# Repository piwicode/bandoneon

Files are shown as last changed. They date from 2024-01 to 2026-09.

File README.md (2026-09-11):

Bandolibre keyboard

🇬🇧 **English** | 🇫🇷 [Français](README.fr.md) | 🇪🇸 [Español](README.es.md)

# Bandolibre

An open-source MIDI controller that brings the Argentine bandoneon into the digital age.

**Bandolibre focuses on one goal:** turning key presses and bellows movement into MIDI — faithfully, instantly, and without the cost or noise of an acoustic instrument. Plug it into any computer, tablet, or phone over USB and you're ready to play, compose, or practice.

An open initiative by [L'Atelier du bandonéon libre](https://github.com/bandolibre)

---

## See it play

Bandolibre demo with a clarinet virtual instrument (https://youtu.be/6s1wlRKlAk4)

Watch the demos: [with a clarinet virtual instrument](https://youtu.be/6s1wlRKlAk4) · [with strings virtual instruments](https://youtu.be/nJ0j7DtbYDk).

---

## Who is it for?

- **Students** who don't own an instrument yet and want to start learning
- **Players** who want to practice silently — at home, on the road, at any hour
- **Composers** entering scores into notation software one note at a time
- **Musicians** triggering synths and samplers on stage or in the studio

---

## How it works

- **142-key Rheinische Lage layout** — both hands, exact fingering of the Argentine bandoneon
- **Hall-effect sensors** on every key — no mechanical contact, no wear, scanned 2400 times per second
- **Blade spring + sensor pair** for the bellows — measures push/pull effort and emits MIDI CC#11 (Expression), just like the real thing
- **Two 6.35 mm expression pedal inputs** — compatible with M-Audio EX-P pedals; pedal 1 sends CC#1 (Modulation), pedal 2 sends CC#4 (Foot Controller)
- **USB-MIDI** out of the box — plug into any DAW, notation app, or synth; no drivers needed

---

## Features

**Keyboard tuning** — a button cycle through the three keyboard layouts: Rheinische Tonlage (bisonoric, 142 tones), Peguri, or Manoury.

**Table mode** — a button toggles table mode: keys fire immediately at fixed velocity, no bellows movement required. Handy for entering a score note by note without working the bellows.

**Play anywhere** — Bandolibre is bus-powered over USB; any phone, tablet, or laptop with a soft synth becomes the sound engine. A small USB hub with a headphone jack and a power pass-through gives you audio, charging, and MIDI from a single cable — tested and pocket-sized.

**Adaptable** — standard USB-MIDI is compatible with the whole adapter ecosystem: plug in a USB Bluetooth MIDI adapter to play wirelessly, or a USB-to-DIN-5 adapter to drive vintage hardware synths.

---

## Anyone can build it

This is a fully open DIY project. PCBs are designed for economic JLCPCB two-layer fabrication — affordable and easy to order. The mechanical parts are 3D-printable (a FabLab near you works great). Firmware is open-source and flashable with a standard [ST-LINK probe](https://www.st.com/en/development-tools/stlink-v3minie.html) and a [TC-2070-IDC-050](https://www.tag-connect.com/product/tc2070-idc-050) cable.

Building one costs about as much as a decent MIDI keyboard or a good pair of studio headphones like the DT-770 Pro.

---

## Bill of Materials

| Part | Qty | Notes |
|---|-----|---|
| 3D-printed body parts + 71 keys | — | ~880 g filament, ~24 h print time, [STEP files](https://github.com/bandolibre/bandolibre.github.io/releases)|
| Electronics board: Main, left and right PCBs  | 1 | [EasyEDA design](boards), [Gerber files](https://github.com/bandolibre/bandolibre.github.io/releases) |
| Hall-effect switches | 71 | [GATERON Low Profile Magnetic Jade HE](https://www.gateron.com/products/gateron-low-profile-magnetic-jade-switch?VariantsId=10872) |
| Bellows spring strip | 1 | [65Mn spring steel, 1.2 × 40 × 300 mm](https://fr.aliexpress.com/item/1005006952720032.html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) |
| Permanent magnets 14.5 × 6 × 2 mm | 2 |  |
| M4 × 30 socket head cap, stainless A2 | 4 | [supplier](https://www.vis-express.fr/vis-metaux-inox-a2-chc-btr-cle-de-8-hc8-filetage-total-din-912-din-912-iso-4762/36756-927484-vis-metaux-inox-a2-chc-btr-cle-de-3-hc3-m4x40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)|
| M4 × 10 × 0.8 flat washer, stainless A2 | 4 | [supplier](https://www.vis-express.fr/rondelle-plate-m-inox-a2-nfe-25513vs-nfe25513-grade-c/36925-940576-rondelle-plate-m4x10x08-m-inox-a2.html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)|
| M3 × 6 socket head cap, stainless A2 | 19 | [supplier](https://www.vis-express.fr/vis-metaux-inox-a2-chc-btr-cle-de-8-hc8-filetage-total-din-912-din-912-iso-4762/36726-2595617-vis-metaux-inox-a2-chc-btr-cle-de-25-hc25-m3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)|
| M3 × 8 socket head cap, stainless A2 | 11 | [supplier](https://www.vis-express.fr/vis-metaux-inox-a2-chc-btr-cle-de-8-hc8-filetage-total-din-912-din-912-iso-4762/36728-2610009-vis-metaux-inox-a2-chc-btr-cle-de-25-hc25-m3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) |
| M3 × 12 socket head cap, stainless A2 | 4 | [supplier](https://www.vis-express.fr/vis-metaux-inox-a2-chc-btr-cle-de-8-hc8-filetage-total-din-912-din-912-iso-4762/36731-2616466-vis-metaux-inox-a2-chc-btr-cle-de-25-hc25-m3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) |
| M3 × 18 socket head cap, stainless A2 | 4 | [supplier](https://www.vis-express.fr/vis-metaux-inox-a2-chc-btr-cle-de-8-hc8-filetage-total-din-912-din-912-iso-4762/36734-2596394-vis-metaux-inox-a2-chc-btr-cle-de-25-hc25-m3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) |
| Adhesives | 2 drops | Loctite 480 |
| USB Type-B cable | 1 | |
| Ribbon cable, FC 1.27 mm, 12P (2×6), 10 cm | 2 | [supplier](https://fr.aliexpress.com/item/1005005058041580.html) |

The full list, including tools and consumables, is in [`documentation/assembly_instructions.md`](documentation/assembly_instructions.md).

They are best built in batches of five — JLCPCB minimum orders make that the natural unit. Team up with friends or reach out to [L'Atelier du bandonéon libre](https://github.com/bandolibre) to express interest in a community build.

At fifty units, PCB fabrication and Gateron switches — the two biggest line items — drop by half again.

---

## Design

overview

The mechanical parts are modeled in Onshape — [the full 3D model](https://cad.onshape.com/documents/313e70e978bf056a8dd7d76c/v/5c5fbc4088ac379c1bd1b53a/e/c6a89cb028bdc195ff70596f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) is public and interactive. Reference [photography](keyboard_picture/) of real instruments was used to accurately reproduce the shape, key placement, and keyboard tilt of both hands.
handle_layout
keyboard_layout

The PCBs are designed with EasyEDA.
3d_pcb

The bellows is replaced by a **blade spring instrumented with two Hall-effect sensors** that read its flexion. Load cell solutions were ruled out early — they are too rigid and remove the tactile feedback players rely on to feel and modulate their effort — it plays like pressing on a wall. The blade spring preserves that proprioceptive feedback while being simple and durable. Blade thickness can be chosen to tune the instrument's stiffness, from light to firm.

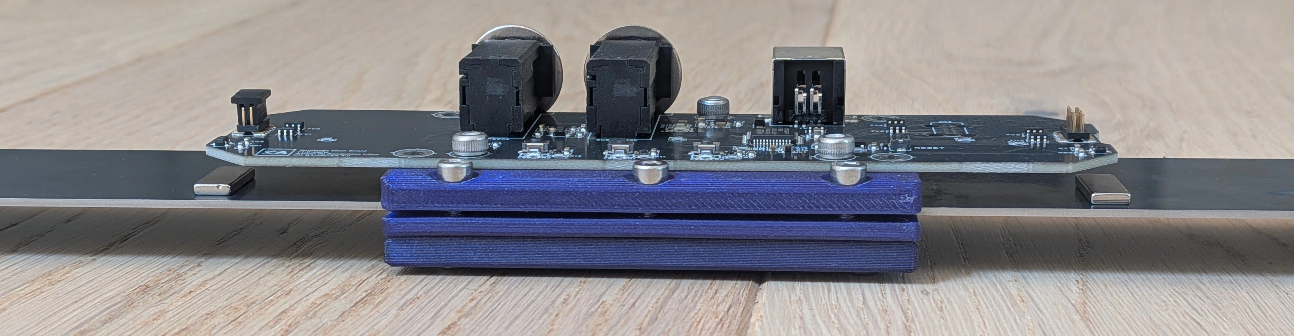
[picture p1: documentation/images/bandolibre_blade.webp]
blade spring


A sensitivity selector button cycles through three amplification levels so the player can adjust how much bellows travel is needed to reach full expression — useful for quiet practice or a stiffer spring.

For a detailed breakdown of the firmware behavior and controls, see [`documentation/features.md`](documentation/features.md).

---

## Build it

- **Hardware & assembly:** see [`documentation/assembly_instructions.md`](documentation/assembly_instructions.md)
- **Firmware:** see [`code/`](code/) — build with `just build` and `just flash`, flash via ST-LINK

---

## Sound

The best match so far is the **SWAM** family of simulation instruments from [Audio Modeling](https://audiomodeling.com/): they are physically modelled rather than sampled, so CC#11 continuously drives the model itself. Bellows intensity comes out as real dynamics — timbre changing with pressure, notes swelling and dying under the bellows — instead of a volume fade over a fixed sample. [Native Instruments Session Strings](https://www.native-instruments.com/en/products/komplete/cinematic/session-strings-2) also works very well.

Modern bandoneon libraries, oddly enough, work poorly for us. They either assume the wrong keyboard layout — chromatic or accordion mappings, with no push/pull distinction — or offer only shallow CC#11 support, with dynamics baked into velocity-triggered samples that the bellows cannot reshape once a note has started.

For practice — and especially on a phone — a simple bandoneon soundfont is enough: [European Bandoneon V2.5 by Jörg Bleymehl](https://musical-artifacts.com/artifacts/1862) gives good results. It loads in any SF2-capable player, costs almost nothing in CPU, and turns a phone or tablet into a usable practice rig without a laptop or a plugin host.

So we are actively looking for virtual instruments with deep expressive support — rich polyphony and CC#11 as a primary articulation driver. If you know of one, or want to help build something tailored to the bandoneon, suggestions and contributions are very welcome.

---

## Where we are

<p>
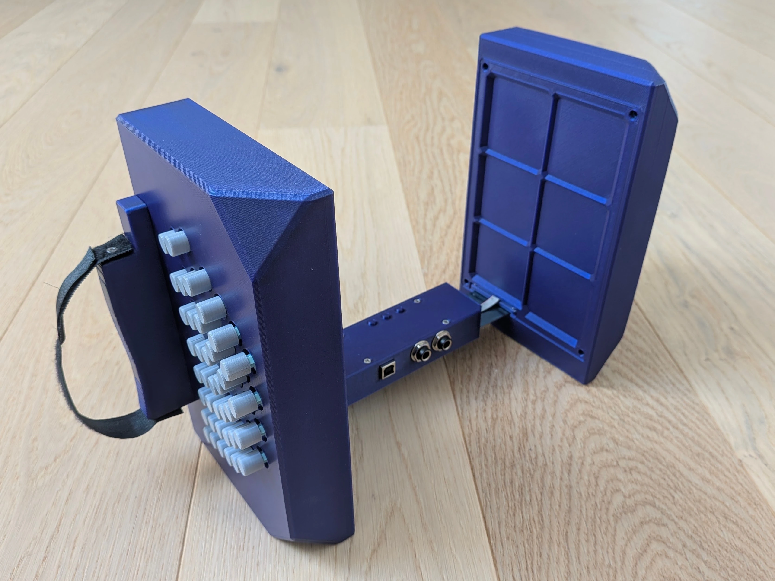
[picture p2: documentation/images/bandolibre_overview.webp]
Bandolibre overview
  
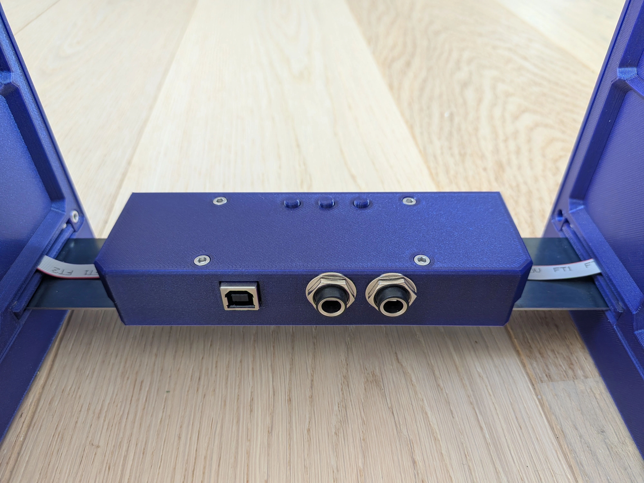
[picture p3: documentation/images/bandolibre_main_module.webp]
Bandolibre main module
  
</p>

Five units are built and working. The firmware handles all 142 keys, bellows push/pull, pedals, and MIDI output reliably. These instruments are currently on loan to bandoneon teachers who are giving us hands-on feedback while we polish the software.

The 3D models and PCB designs are solid — no rework planned there. The active focus right now is tuning the bellows simulation: getting the inertia model right so that short notes feel like the real instrument, not like a sensor.

There is a lot to explore on the software side. Because Hall-effect sensors measure key position continuously — not just on/off — the firmware has access to the full travel of every key at all times. This opens the door to **MPE (MIDI Polyphonic Expression)**: per-note pressure, slide, and lift curves, independently for each of the 142 keys simultaneously.

---

## How to get a device

Bandolibre stays a DIY project: the design is open and anyone can build one. We are polishing the software and collecting feedback on the hardware.

We also miss the paperwork that would allow the association handle a transaction  — passing on boards, a kit, or a finished instrument to someone who asks. 

If you'd like to hear from us when it becomes possible:

<div align="center">

### ✉️ **[Join the interest list →](https://forms.gle/amgxEX4XTy9Jfd538)**

</div>

It is useful for us to see how many people are interested and what they'd play it for. Your answers stay with the association and are only used to contact you about Bandolibre.

---

## Community

Questions, ideas, or just curious?
Join [L'Atelier du bandonéon libre](https://bandolibre.github.io).

The main board communicates digitally with the wing boards and can support any layout. It is possible to design a new keyboard for a different system — Rheinische Lage, Club, Einheitsbandoneon — and reuse the main board.

Working on something similar? Let the association know — we'd love to connect.

---

## Further readings

- [Other electronic bandoneon projects](documentation/other-projects.md)

---

## License



Free to build, modify, and share for non-commercial use.

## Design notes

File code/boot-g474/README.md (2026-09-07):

# UF2 bootloader (main board)

Lets the main board be reflashed by copying a file onto a USB drive, with no
ST-Link, no toolchain and no cable other than the one already carrying MIDI.

Hold **FN2** (the rightmost function button) while powering the instrument on,
and a drive called `BANDOLIBRE` appears. Drop `main-g474.uf2` on it; when the
copy finishes the drive disappears and the instrument restarts on the new
firmware. End-user instructions are in
[documentation/firmware_update.md](../../documentation/firmware_update.md).

## Flash layout

The STM32G474CBT6 has 128 KB of flash, shared:

| Address | Size | Contents |
|---|---|---|
| `0x08000000` | 32 KB | this bootloader (currently ~14 KB used) |
| `0x08008000` | 94 KB | application, Release build (currently ~69 KB used) |
| `0x0801F800` | 2 KB | reserved for the properties store, not yet used |

[`memmap.h`](memmap.h) is the single source of truth for these numbers; four
other files repeat them and [`code/tests/test_dfu_config.py`](../tests/test_dfu_config.py)
fails if any of them drifts.

**The Debug build of the application does not fit in this layout.** At `-O0` it
is ~116 KB, more than the 94 KB above the bootloader and more than what is left
above any bootloader large enough to hold TinyUSB and the MSC class. So there
are two application memory maps:

| | Linker script | Links at | Installed by |
|---|---|---|---|
| Debug | `STM32G474XX_FLASH.ld` | `0x08000000`, 126 KB | `just flash` — **replaces the bootloader** |
| Release | `STM32G474XX_FLASH_APP.ld` | `0x08008000`, 94 KB | `just flash_release`, or a `.uf2` over USB |

`just flash` therefore leaves a board with no DFU support; `just flash_release`
in `../main-g474` puts the bootloader and a Release image back.

## Boot sequence

1. Reset lands here, always.
2. Clocks come up exactly as in the application's `SystemClock_Config()`:
   96 MHz core from the HSI16 PLL, USB on HSI48 trimmed by the CRS against USB
   start-of-frame. The board is crystal-less, so the CRS is not optional.
3. `HAL_MspInit()` clears the UCPD dead-battery pull-down — see the warning
   below.
4. DFU mode is entered if **any** of:
   - PB4 (`SW_FN2`) reads low, i.e. the button is held;
   - the word at `BOOT_FLAG_ADDR` holds `BOOT_FLAG_MAGIC`, written by the
     application's `dfu` console command just before a system reset;
   - the application's vector table fails a sanity check, so a board with
     missing or half-written firmware recovers on its own.
5. Otherwise it de-initialises everything, points `SCB->VTOR` at `APP_BASE`,
   loads the application's stack pointer and jumps to its reset handler.

## Why UF2 rather than copying a `.bin`

A UF2 file is a flat sequence of 512-byte blocks, each carrying the address it
belongs at, a family id identifying the chip, and its position in the file.
[`msc_disk.c`](msc_disk.c) inspects every sector the host writes to the volume,
keeps the ones that are UF2 blocks for an STM32G4 inside the application
region, and throws away everything else — directory entries, FAT updates, and
the `.Spotlight-V100` and `System Volume Information` debris that macOS and
Windows leave on any removable drive.

That means no filesystem code at all: no directory to parse, no cluster chain
to follow, and no assumption about the order in which a host flushes its
writes. Recognising a plain `.bin` would need all three, and each is a place
for a host-specific quirk to corrupt an image. It is also why every
drag-and-drop bootloader (Adafruit, RP2040, micro:bit) uses UF2.

Blocks are staged in RAM and only written to flash once all of them have
arrived, so an interrupted or truncated copy never reaches the chip. The
bootloader has the RAM to spare: the application uses 8 KB of the 128 KB.
`flash_write_app()` then programs the page holding the vector table **last**,
so a power cut during the ~1 s write leaves an image that fails the validity
check and the board comes back up in DFU mode rather than jumping into
something half-written.

## ⚠ PB4 needs the UCPD dead-battery pull-down cleared

`SW_FN2` sits on PB4, which is also **UCPD1_CC2**. Out of reset that pin can
carry a 5.1 kΩ pull-down from the UCPD peripheral, gated by the level on PA10
(STM32G474CB datasheet, pin table note 6). PA10 is this board's `USART1_RX`,
which the attached ST-Link VCP holds high while idle — so the pull-down is
active, it beats the ~40 kΩ internal pull-up, and the button reads as pressed
forever. `HAL_PWREx_DisableUCPDDeadBattery()` in `HAL_MspInit()` removes it,
and `test_dfu_config.py` checks the call is still there.

PB4 is also `NJTRST` and comes out of reset in its JTAG alternate function
(note 5), so it has to be claimed as a plain input. The board is debugged over
SWD, which does not use that pin.

FN0 was **not** used for this: it sits on PB8/BOOT0 and drives BOOT0 *high*
when pressed, which would collide with ST's own boot-mode selection if the
`nBOOT_SEL` option byte were ever cleared.

## USB identity

| | Application | Bootloader |
|---|---|---|
| VID:PID | `0483:a5b4` | `0483:a5b4` |
| bcdDevice | `0x0100` | `0x0200` |
| Class | MIDI (IAD) | Mass storage |
| Product | Bandolibre | Bandolibre DFU |
| Serial | 96-bit chip UID, 24 hex digits | same |

The VID/PID is ST's vendor id with a product id sublicensed to this project
(see [`../main-g474/usb/README.md`](../main-g474/usb/README.md)). One product id
covers the whole product, so application and bootloader share it and differ by
`bcdDevice` instead: hosts cache a driver per VID/PID/revision, and the two
expose different classes.

## Build

Not a CubeMX project — there is no `.ioc` and no generated `Core/`. It
configures its handful of peripherals directly, so there is no second generated
project to keep in sync with the hardware. It does reuse the main board's
vendored HAL and startup file rather than carrying a second copy, the same way
both boards reuse `../common`.

```sh
just build          # Debug (also -Os; the bootloader must fit either way)
just build_release  # what ships
just size           # how much of the 32 KB region is used
just flash          # install at 0x08000000, leaving the application intact
```

`just flash` goes through `../tool/flash.py` with the board type `main-g474`,
so the chip-UID registry still refuses to write main board firmware to a wing.

## Testing

```sh
lsusb -d 0483:a5b4              # bootloader enumerated (bcdDevice 0200)
cat /media/*/BANDOLIBRE/INFO_UF2.TXT
```

The bootloader prints to the same console as the application (USART1 on PA9,
921600 baud, TX only), which is the fastest way to see why an update did not
take:

```
boot-g474: soft_request=0 button=1 app_valid=1
boot-g474: entering DFU mode
uf2: all 270 blocks received (image_len=69116)
flash: writing 69116 bytes, page=2048 bytes, 34 pages, DBANK=1, FLASHSIZE=128 KB
```

Every page is read back after erasing and the commit is abandoned if one did
not clear, so a failure names the address rather than silently writing a
corrupt image.

Things worth exercising after a change, all of which must leave a working
board: unplug mid-copy; copy an unrelated file; copy a `.uf2` built for
`0x08000000`; delete a file from the volume.

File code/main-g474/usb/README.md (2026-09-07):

# USB stack (TinyUSB)

The main board enumerates as a full-speed MIDI USB device built on
[TinyUSB](../../third_party/tinyusb) (git submodule, `code/third_party/tinyusb`):

| | |
|---|---|
| VID / PID | `0x0483` / `0xA5B4` (ST's vendor id, product id sublicensed from ST) |
| Manufacturer | L'Atelier du bandonéon libre |
| Product | Bandolibre |
| Serial | 96-bit chip UID, 24 hex digits |
| Interfaces | MIDI only |

`0x0483` is STMicroelectronics' USB-IF vendor id; `0xA5B4` is a product id
sublicensed from ST for this project, valid only for a product built on ST
silicon (STM32G474CBT6) and only for Bandolibre. The sublicense does not carry
USB-IF certification, so the instrument must not display the USB logo. Earlier
revisions used TinyUSB's development ids `0xCafe` / `0x4008` (`0x4000 |`
interface bitmap, computed by a `PID_MAP` macro); that macro is gone, the
product id is now fixed.

The board also carries a [UF2 bootloader](../../boot-g474/README.md), which
enumerates while firmware is being updated — mass storage, product string
"Bandolibre DFU". It shares this VID/PID (one product id covers the product)
and is told apart by `bcdDevice`: `0x0100` here, `0x0200` in the bootloader.
The revisions must differ because hosts cache a driver per VID/PID/revision and
the two devices expose different classes.

## Files

- `tusb_config.h` — TinyUSB feature configuration (device-only, MIDI).
- `usb_descriptors.c` — device/configuration/string descriptors. Strings are
  UTF-8 and converted to UTF-16 on the fly, so accented names work.
- `usb_app.c/.h` — glue: `usb_app_init()` starts the stack (called from
  `main()` after `MX_USB_PCD_Init()`), `usb_app_task()` runs `tud_task()` from
  the main loop, and the three USB IRQ handlers (which override the weak
  symbols in `startup_stm32g474xx.s`).

The TinyUSB sources, include paths, and the `CFG_TUSB_MCU=OPT_MCU_STM32G4`
define are listed in the user sections of [CMakeLists.txt](../CMakeLists.txt).

## How it coexists with CubeMX

CubeMX still generates `MX_USB_PCD_Init()` (HAL PCD), which enables the USB
peripheral clock via `HAL_PCD_MspInit()`. TinyUSB's `dcd_init()` then resets
and takes over the peripheral; `HAL_PCD_Start()` is never called, so the HAL
never enables the DP pull-up or the USB interrupts itself. Don't remove the
USB peripheral from the `.ioc`.

**USB clock**: the board is crystal-less, so the `.ioc` selects HSI48 as USB
kernel clock, trimmed by the CRS against USB SOF (the PLL alternative is fed
by HSI16, ±1%, outside the USB FS ±0.25% budget). All of this lives in the
generated `SystemClock_Config()`. These `.ioc` invariants — HSI48 + CRS, USB
device FS enabled, USB interrupts *not* enabled in the NVIC tab (TinyUSB owns
the handlers) — are checked by `code/tests/test_usb_config.py` (`just test`
from `code/tests`).

## Testing

```sh
lsusb -d 0483:a5b4       # device present (bcdDevice 0200 = bootloader, see boot-g474)
amidi -l                 # MIDI port listed as "Bandolibre"
aseqdump -p Bandolibre &   # then run `midi [note]` in the console to test
```

The `midi [note]` console command (via USART1/ST-Link) sends a note-on/note-off
pair (default 69 = A4) for end-to-end checking over USB MIDI.

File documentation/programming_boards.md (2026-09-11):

## Connecting the debugger probe

Plug the ST-Link into a USB port and verify the device is detected:

```
$ lsusb | grep STLINK
Bus 001 Device 070: ID 0483:3754 STMicroelectronics STLINK-V3
```

Install [stlink-tools](https://github.com/stlink-org/stlink) from source, in a
directory next to your `bandolibre` checkout:

```
sudo apt remove stlink-tools
sudo apt install build-essential cmake libusb-1.0-0-dev
git clone --depth 1 --branch testing https://github.com/stlink-org/stlink
cd stlink
git apply ../bandolibre/documentation/0001-fix-st-trace-fix-SWO-trace-on-STLINK-V3-HS-bulk-endp.patch
make release && sudo make install && sudo ldconfig
```

Once the ST-Link is plugged into the board:

```
$ st-info --probe
Found 1 stlink programmers
  version:    V3J15
  serial:     002F00413235510637333439
  flash:      131072 (pagesize: 2048)
  sram:       131072
  chipid:     0x469
  dev-type:   STM32G47x_G48x
```

## Install build prerequisites

The ARM toolchain and the build backend:

```
sudo apt install gcc-arm-none-eabi ninja-build
```

I use [`just`](https://just.systems/) to run commands from a configuration file
such as `code/main-g474/justfile`:

```
curl --proto '=https' --tlsv1.2 -sSf https://just.systems/install.sh | bash -s -- --to DEST
```

or

```
cargo install just
```

## Checkout the source code

```
git clone --recurse-submodules https://github.com/bandolibre/bandolibre.git
```

## Build the firmware

Generate the build system once, then build:

```
cd code/main-g474
just init_build_release build_release
```

## Flash the firmware

Flashing wing firmware onto a main board — or the reverse — drives pins against
the connected hardware and can damage the boards, so a chip must be registered
before it can be flashed. `code/tool/boards.csv` maps each STM32 unique device
ID to its board type, and is checked before every flash.

Register a board once, before its first flash:

```
cd code/main-g474
just registry_add
```

Then flash with:

```
cd code/main-g474
just flash_release
```

`just flash_release` programs every connected ST-Link whose chip is registered
as that board type, so both wings can be flashed in a single command.

The same recipe apply in `code/wing-g474`.

## Main board: two images, two memory maps

The main board carries a UF2 bootloader at `0x08000000` so it can be updated by
copying a file onto a USB drive — see
[firmware_update.md](firmware_update.md) and
[code/boot-g474/README.md](../code/boot-g474/README.md). That splits its 128 KB
of flash, and the Debug build does not fit in the application's share of it:
at `-O0` it is ~116 KB against the 94 KB available above the bootloader. So the
two configurations link differently, and the recipes differ accordingly:

| Recipe | Builds | Links at | Bootloader after |
|---|---|---|---|
| `just flash` | Debug, `-O0 -g3` | `0x08000000` | **erased** — this image takes its place |
| `just flash_release` | bootloader + Release, `-Os -flto` | `0x08008000` | installed |
| `just dfu` | Release, packaged as `.uf2` | `0x08008000` | (no flashing; copy over USB) |

Day-to-day development is unchanged: `just flash` still gives a full `-O0 -g3`
image with all its debug information, it just has no DFU drive. Run
`just flash_release` when you want the bootloader back, and once per board
before handing it to anyone who will update it over USB.

`just dfu` is the one to use for a release: it builds the Release
configuration and writes `build/Release/main-g474.uf2`.

None of this affects `code/wing-g474`, which has a single memory map.

## Read UART debug console

Characters written with `printf` (via `_write` retargeted to `HAL_UART_Transmit`) are sent over USART to the STLink VCP bridge, which forwards them to a host `/dev/ttyACMx` device.

Use `tio` to read it — it auto-reconnects across resets, unlike `screen` or `cat`:

```bash
tio /dev/serial/by-id/usb-STMicroelectronics_STLINK-V3_*
```

The glob resolves to the correct `/dev/ttyACMx` regardless of what other USB serial devices are present. Or via the justfile recipe:

```bash
just console
```

Press `ctrl-t q` to quit.

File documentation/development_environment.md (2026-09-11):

# Development environment

For development I use VSCode with `clangd` rather than `intelliSenseEngine` because it reads `compile_commands.json` directly — correct ARM toolchain headers, exact build flags, no manual config.

Make sure clangd is installed on your system:

```bash
sudo apt-get install -y clangd && clangd --version
```

# Read SWO debug text stream

SWO is not used by the project (USART is more reliable).
Here is how to use it for reference.

Characters written to `ITM_SendChar` show up in a view named
`SWV ITM Data Console`, but its configuration button does not work, so the view
falls short.

```
st-trace --clock=16m
```

Warning: This requires a patch of st-trace(0001-fix-st-trace-fix-SWO-trace-on-STLINK-V3-HS-bulk-endp.patch) otherwise it will fail with `2026-06-08T23:00:36 ERROR usb.c: read_trace insufficient buffer length`

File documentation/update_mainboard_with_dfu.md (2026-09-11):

# Update the main board software

- Keep the left-most button pressed while plugging the Bandolibre USB to a
  computer
- The Bandolibre should be detected as new storage device.
- Drop the file `main-g474.uf2` to this storage.
- Upon sucessfull update drive should disaper and the Bandolibre software is now
  up to date.

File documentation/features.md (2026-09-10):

# Features

## Keyboard tuning (FN2)

The wing boards report which side they are (left or right); the notes those
buttons play are chosen by the `keyboard_tuning` property, so one firmware
covers several bandoneon systems on the same hardware. The **right function
button (FN2)** cycles through them, wrapping after the last, and the tuning now
selected is reported on the console. FN2 only writes the property, so the button
and `set keyboard_tuning` stay in agreement.

| Value | System | |
|---|---|---|
| 0 | **Rheinische Tonlage**, 142 tones (default) | bisonoric |
| 1 | **Peguri** | unisonoric |
| 2 | **Manoury** | unisonoric |

*Bisonoric* means a key sounds a different note depending on whether the bellows
is pushed or pulled — the traditional Argentine bandoneon. The two French
systems are *unisonoric*: every key sounds the same note in both directions.
All three share the same button disposition, so switching tuning changes only
which note each button plays.

Two notes of the published Peguri/Manoury right-hand keyboard are missing here.
Those layouts use 40 right-hand buttons where this instrument has 38, and the
two absent buttons are the lowest of their rows (D4 and D♯4). What remains is
chromatically complete from E4 upward.

Changing the tuning while keys are held is safe: a sounding note keeps its
original pitch until released, and the next press uses the new tuning.

Note that property storage is still RAM-only, so the tuning returns to
Rheinische after a power cycle.

## MIDI Active Sensing

A heartbeat the device sends to the host so the host can detect a dropped
connection and cut the sound (silence stuck notes) when the heartbeat stops.

Settings:
- `midi_active_sensing_enable` — send the heartbeat (default on).
- `midi_active_sensing_period` — milliseconds between bytes (default 200).

## Table mode

The **left function button (FN0)** toggles table mode on and off; the current
state is reported on the console.

Normally a note only sounds while the bellows is moving, and its pitch and
velocity follow the bellows direction and intensity. Table mode lets the
instrument be played flat on a table with the bellows at rest: each key press
sounds immediately and the bellows is treated as always **pulled**, so every key
plays its pull note. This makes it practical to type a score into a DAW or
notation software one note at a time, without having to work the bellows.

With the bellows at rest it can shape neither loudness nor expression, so table
mode holds both constant and stops the bellows driving them:

- every note plays at the same velocity;
- the expression CC (**CC#11**) is no longer sent from the bellows. It is pinned
  once, on entering table mode, to that same value. Without this the bellows
  would sit at rest, hold CC#11 at 0, and silence every note.

Both take their value from `tablemode_velocity` (default 80).

Toggling table mode off re-evaluates the keys currently held so sounding notes
follow the real bellows again, and hands CC#11 back to it.

## Bellows sensitivity

The **middle function button (FN1)** cycles bellows sensitivity through three
levels, wrapping back to the first; the current level is reported on the
console. Each level scales the bellows signal (the 0..1024 intensity that drives
both note velocity and the expression CC), so a higher level reaches full
velocity and full expression with less bellows travel — useful for quiet playing
or a stiff bellows.

Level 1 is unity (no scaling). Levels 2 and 3 multiply by `bellow_scale_mid`
(default x1.5) and `bellow_scale_high` (default x2.0); both are stored as a /256
fixed point value (256 = x1.0), so 384 and 512. The scaled intensity is clamped
to its full range, so beyond the point that reaches maximum the signal simply
saturates.

Table mode has no bellows signal to scale, so the sensitivity levels do not
affect it; it plays at `tablemode_velocity` whatever the level.

## Bellows inertia mode

Set `bellow_inertia_enable` to turn bellows inertia mode on; it is **off by
default**. Off, the bellows reading drives the sound
directly. On, the reading is run through a virtual-bellows pressure model that
gives the light blade spring the feel of an acoustic bandoneon's bellows: a quick
impulse stores energy that stays available for the note played just after, held
chords soften as air escapes through the open pallets (pressed keys), and the
push/pull direction is committed so it does not flicker near rest.

The behaviour is shaped by the `bellow_inertia_*` properties (responsiveness,
damping, impulse strength, air leak, and the direction deadzone/hysteresis). See
[bellow_simulation.md](bellow_simulation.md) for the principle, the model, and a
tuning guide.

## Pedals

Two pedal inputs, each accepting an expression pedal wired like the M-Audio
EX-P (mode switch set to **M-Audio**). A plugged-in pedal is read continuously
and sent on both keyboard channels: pedal 1 on the **Modulation wheel (CC#1)**,
pedal 2 on the **Foot Controller (CC#4)**. Both are pre-mapped in most
instruments, so the pedals are expressive out of the box, and either can be
MIDI-learned to another VST parameter in the DAW.

Per pedal, `pedalN_min`/`pedalN_max` set the raw ADC readings that map to CC 0
and CC 127; values between are interpolated linearly and values outside are
clamped. Setting this window inside the pedal's full travel lets the usable
stroke span the whole MIDI range. To calibrate, push the pedal to each extreme
and use the raw ADC readings there as min and max.

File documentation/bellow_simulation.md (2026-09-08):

# Bellows inertia simulation

A virtual-bellows model that gives the lightweight blade-spring instrument the
feel of an acoustic bandoneon's bellows. It is switched by the
`bellow_inertia_enable` property and is **off by default**; with it off, the
bellows reading drives the sound directly (the plain mode). This document explains the principle, the
model, and how to tune it.

## Why

The blade spring is read by a pair of Hall-effect sensors that measure its
flexion. That flexion tracks the **force** the player applies through the hands
and knees, and it reads faithfully while the force is steady or changing slowly.

An acoustic bandoneon's bellows, however, has mass and encloses a volume of air.
Two things follow that the bare blade does not reproduce:

- **Inertia.** A quick heel or hand *impulse* sets the heavy bellows moving and
  that motion persists for a moment. Players exploit this: they give an impulse
  *before* a note and play the note in the short window after, spending the
  stored energy as attack. The light blade instead just springs back and bounces.
- **Air escaping through the open pallets.** Pressure in the bellows is what
  drives loudness. It builds as the bellows is worked and bleeds away as air flows
  out through whichever pallets are open — and a pallet opens when its **key** is
  pressed, whether or not the reed is sounding yet. So a held chord softens unless
  the player keeps pushing, pressure is conserved while no key is held, and keys
  held down at rest already bleed the pressure of an impulse that follows.

The inertia mode models a bellows with these properties and uses its simulated
**pressure** as the intensity that sets note velocity and expression.

## Principle

The model is a small lumped-physics system, integrated once per bellows poll. It
is **algebraic**: pull is positive, push is negative, so push and pull energy stay
separate and a pull impulse never leaks into a push note.

| Physical quantity | In the model |
|---|---|
| Player force on the bellows | `F` — signed live reading (magnitude × direction) |
| Bellows mass / momentum  | `v` — bellows velocity (carries the inertia) |
| Chamber pressure (loudness) | `P` — the model output, becomes the intensity |
| Air escaping through open pallets | a leak on `P` that grows with the number of pressed keys |

The player's force accelerates the bellows mass; the moving bellows pumps the
chamber pressure; the pressure pushes back on the bellows and bleeds out through
the open pallets. Worked steadily, the pressure settles to the applied force, so the
output reaches the input. Hit with a brief impulse, the momentum keeps pumping the
pressure after the force is gone, leaving it elevated for the short window the
player plays into.

## Model

State `v` and `P` are kept across polls; `F` is the signed live reading and `n`
the number of keys held down (open pallets, regardless of bellows direction). With
`dt` the time since the last poll (clamped to guard against a stalled loop):

```
omega = 1000 / track_ms            angular speed at which pressure tracks force
zeta  = damping / 256              damping ratio (256 = critically damped)
L     = (leak_quiet + n * leak_per_key) / 256   total leak rate, per second

v += impulse_gain/256 * (F - F_prev)                  impulse kick from flexion speed
v += (omega^2 * (F - P) - 2*zeta*omega * v) * dt      force drives the damped bellows
P += v * dt                                            the moving bellows pumps pressure
P *= max(0, 1 - L * dt)                               open pallets bleed pressure
P  = clamp(P, -1024, +1024)
```

- **Converges to zero at rest.** When the raw hall reading is within the plain-mode
  deadzone (entry at `dead/2 + hyst/2` from centre, 30 ADC units with defaults),
  the driving force is set to `F = 0`. The oscillator then drives `P` toward 0 and
  the leak decays it the rest of the way. This means any calibration offset within
  the deadzone — typically a few ADC counts — never prevents `P` from settling to
  zero when the bandoneon is left on a table.

- **Reaches the input.** With no key held the system is a damped oscillator
  driven toward `F`. At a steady force and no keys, `P` settles to:

  ```
  P_ss = F / (1 + 2·zeta·leak_quiet/(256·omega))
  ```

  With the defaults (`track_ms=40`, `damping=256`, `leak_quiet=64`):
  `omega=25`, `zeta=1`, `L_quiet=0.25/s` → `P_ss ≈ 0.98·F` (2% below F).
  This small droop is the resting feel of a bellows that still bleeds slightly
  at rest. Set `leak_quiet = 0` to eliminate it and make the model converge
  exactly onto the plain (naive) output at steady force.

- **With held keys.** Each pressed key raises the leak rate by `leak_per_key/256`
  per second. With 5 keys and the defaults, the total leak `L ≈ 2.75/s` and
  `P_ss ≈ 0.82·F` (18% below F). The player must push harder to sustain a
  full chord, exactly as on the acoustic instrument.

- **Stored energy.** A brief spike in `F` injects velocity `v`; after the force
  returns, `v` keeps pumping `P` for roughly `1 / omega`, the window that carries
  the impulse into the note.

- **Flexion speed.** Fast flexion drives the stored energy two ways: through the
  lag error `F - P` (large only when the force outruns the smoothed pressure) and
  through the explicit `impulse_gain * (F - F_prev)` term, which catches a sharp
  impulse a sluggish oscillator would otherwise miss. Setting `impulse_gain` to 0
  leaves the pure oscillator.

- **Damping.** At critical damping (`zeta = 1`) the bellows does not overshoot or
  ring, unlike the springy blade. Lower values allow a deliberate, expressive
  overshoot.

The integration is semi-implicit (the new velocity pumps the pressure in the same
step), which keeps the oscillator stable, and the leak is a plain factor floored
at zero, which is stable for any step and needs no transcendental.

The model is integrated every poll so its state is always visible on the live
report for tuning; its output is used for sound only while
`bellow_inertia_enable` is set.

## Direction and output

On a bisonoric instrument the push/pull decision selects a *different note*, so it
must not flicker near rest — but the loudness must stay responsive. These are
handled separately:

- **Magnitude.** The intensity is `|P|`, used directly, with no added lag.
- **Direction.** The sign of `P` is committed through a deadzone plus a hysteresis
  margin (the same classifier the plain mode uses on the raw reading): the
  direction only changes by crossing through NEUTRAL, and a margin must be given
  back before it returns to NEUTRAL. So a wobble around zero cannot retrigger the
  opposite note, while a deliberate reversal still passes.

Both `dir_dead` and `bellow_dead` (plain mode) use the same threshold convention:
the **entry threshold** from NEUTRAL is `dead/2 + hyst/2` away from the neutral
centre, and the **return threshold** (direction→NEUTRAL) is `dead/2 - hyst/2`
from centre. With the defaults (`dir_dead=64`, `dir_hyst=32`), direction commits
when `|P| > 48` and releases when `|P| < 16`.

Expression (CC#11) is emitted from the same effective intensity through the shared
hysteresis and rate-limit pipeline used by the pedals: it suppresses jitter, caps
the send rate, and coalesces rather than drops, so the latest value is always
sent. The plain and inertia modes share this one CC pipeline. When the bellow
returns to rest (intensity = 0), CC=0 is sent immediately and the hysteresis
anchor is reset so it does not stick.

## Parameters

All are `bellow_inertia_*` properties, editable live from the console. Fixed-point
values are noted as `/256` (256 = 1.0).

| Property | Default | Meaning / feel |
|---|---|---|
| `track_ms` | 40 | Time for pressure to track force, ms. Smaller is snappier with a shorter impulse window; larger is more sluggish with a longer window. `omega = 1000/track_ms`. |
| `damping` | 256 | Damping ratio `/256`. 256 = critical (no bounce); below that allows expressive overshoot. |
| `impulse_gain` | 64 | Feed-forward `/256` from flexion speed. Raises how strongly a sharp impulse stores energy; 0 disables it. |
| `leak_quiet` | 64 | Pressure bleed rate `/256` per second when no key is held. 0 = no resting drift; higher lets stored energy fade faster at rest. See steady-state formula above. |
| `leak_per_key` | 128 | Extra bleed `/256` per second for each key held (open pallet). Higher makes held chords soften more as more keys are pressed. |
| `dir_dead` | 64 | Neutral deadzone in pressure units (0–1024). Entry threshold is `dir_dead/2 + dir_hyst/2` from zero. |
| `dir_hyst` | 32 | Margin given back before returning to neutral, in pressure units. Larger holds the direction (and a note) longer after the blade returns. |

The expression-CC behaviour reuses the existing `bellow_cchyst` and
`bellow_cc_period_ms`; the FN1 sensitivity scale still applies, since the model is
fed the already-scaled reading.

## Convergence toward plain mode

To make the inertia model feel like the plain (naive) mode:

1. Set `leak_quiet = 0` so `P` converges exactly to `F` at steady force with no
   keys held.
2. Set `dir_dead` to match the plain-mode deadzone in pressure units:
   ```
   dir_dead ≈ (bellow_dead/2 + bellow_hyst/2) / push_span × 1024
   ```
   With the defaults (`bellow_dead=40`, `bellow_hyst=20`, push span ≈ 360 ADC
   units): `dir_dead ≈ 30/360 × 1024 ≈ 85`.
3. Set `track_ms` very small (e.g. 5 ms) so `P` snaps to `F` almost instantly.
4. Set `impulse_gain = 0` to disable the feed-forward kick.

At those settings the output is effectively the naive model filtered through the
same deadzone/hysteresis.

## Tuning

Enable the bellows live report (`show_bellow`) and watch the first line: it shows
the signed `force`, the velocity `v`, the pressure `P`, the committed effective
intensity and direction, and the `keys` count.

1. With `bellow_inertia_enable` off, confirm `P` follows `force` and settles onto it under a slow,
   steady push or pull.
2. Set `track_ms` for the impulse window you want, then `damping` for how much (if
   any) overshoot to allow.
3. Give a sharp impulse and play a note just after; raise `impulse_gain` until the
   stored attack feels right.
4. Hold a chord while pushing and raise `leak_per_key` until the pressure droop
   matches the desired effort.
5. If the direction flickers at rest, raise `dir_dead`; if notes cut off too soon
   after the blade returns, raise `dir_hyst`.

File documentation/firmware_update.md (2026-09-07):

# Updating the firmware

The main board can be updated over the same USB cable it uses for MIDI. No
programmer, no cable other than the one you already have, and nothing to
install.

## Doing the update

1. Unplug the instrument's USB cable.
2. Hold down **FN2**, the rightmost of the three function buttons.
3. Plug the USB cable back in, keeping FN2 held until a drive appears.
4. A drive called **BANDOLIBRE** shows up, the way a USB stick would. Its LED
   blinks slowly while it waits.
5. Copy `main-g474.uf2` onto that drive.
6. The LED blinks faster while the file transfers, then stays lit for about a
   second while the firmware is written. The drive disappears and the
   instrument restarts on the new firmware.

That is the whole process. The drive is not real storage — it exists only to
receive the firmware file, so do not expect files copied there to stay.

## If something goes wrong

**The copy was interrupted, or the instrument lost power partway through.**
Nothing is broken. The new firmware is only written after the whole file has
arrived, so an interrupted copy is simply discarded. Start again from step 1.

**The instrument does not start, and shows the BANDOLIBRE drive on its own
without FN2 held.** This is the recovery path working as intended: the
bootloader checks the firmware before starting it, and falls back to the drive
if it is missing or damaged. Copy the `.uf2` again.

**Nothing happens when you copy the file.** The file has to be a `.uf2` built
for this board. A `.bin`, a `.hex`, or a `.uf2` for another project is ignored —
that is deliberate, so an accidental drag cannot damage the instrument.

**The drive does not appear at all.** Make sure FN2 is held *before* the cable
goes in and stays held for a second or two after. If the instrument is running
normally, you can also reach the drive from the debug console (below).

## Rebooting into the drive without unplugging

If you have the console open (see
[programming_boards.md](programming_boards.md)), the `dfu` command does the
same thing:

```
> dfu
Rebooting into DFU mode; the BANDOLIBRE drive will appear.
```

## For developers: producing the .uf2

```sh
cd code/main-g474
just dfu            # -> build/Release/main-g474.uf2
```

This builds the Release configuration — the one linked to sit above the
bootloader — and packages it. `just build` alone produces a Debug image, which
is a different memory map and **cannot** be distributed this way; `just dfu`
always builds Release for you.

A board that has never had the bootloader installed needs one ST-Link session
first:

```sh
cd code/main-g474
just flash_release  # bootloader + application, over SWD
```

After that it can be updated over USB for good. Note that plain `just flash`
installs the Debug image *over* the bootloader, so a development board loses
its DFU drive until the next `just flash_release`. The reason for the split is
that the Debug build is ~116 KB — too large to fit above a bootloader in the
128 KB this chip has.

The full picture, including the flash layout and why the format is UF2, is in
[code/boot-g474/README.md](../code/boot-g474/README.md).

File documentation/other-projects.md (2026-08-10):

# Related projects

We pay attention to the scene of electronic bandoneon projects. If you are
working on one and would like it mentioned here, reach out — together we are
stronger.

The information below is collected on a best-effort basis from public sources
and may be incomplete or out of date. Corrections are welcome.

## Bandonino

Author
: Danny Chapman

Year
: 2024

Notes
: USB MIDI only. Bellow sensing via a load cell. Unisonoric (Peguri/Manoury layout).

License
: MIT.

References
:   - [Project repository](https://github.com/Rowlhouse/bandonino)
    - [Build and demonstration video](https://www.youtube.com/watch?v=M0wQ6heuBrk)
    - [Playing demonstration video](https://www.youtube.com/watch?v=Qa_-vbLSPUA)
    - [Accordionists Forum thread](https://www.accordionists.info/threads/midi-bandoneon-new-diy-by-danny-chapman.12412/)

## Bandoneón Electrónico para PC

Author
: Leonardo Martinez

Year
: 2024

Notes
: Apparently has no bellow sensing.

License
: None known — likely closed source.

References
:   - [Demonstration video](https://www.youtube.com/watch?v=EJAfWYpv1EE)

## Bandolica

Author
: Mariano Godoy, Sebastián Barbui

Year
: 2022 - 2024

Notes
: Apparently has only the right keyboard and no bellow sensing. Sold as a
  practice device paired with a learning application; connects over USB to a
  computer, later to a phone.

License
: None known — likely closed source.

References
:   - [Demonstration video](https://www.youtube.com/watch?v=CickbQfX_PU)
    - [Presentation video](https://www.youtube.com/watch?v=sE_Qt0a6ZiQ)
    - [La Nación article](https://www.lanacion.com.ar/tecnologia/bandolica-el-bandoneon-digital-hecho-en-la-argentina-para-practicar-con-ese-instrumento-en-cualquier-nid29062022/)

## Bandoneon MIDI

Author
: Pablo Fredes

Year
: 2013

Notes
: Bellow sensing

License
: None known — likely closed source.

References
:   - [Demonstration video](https://www.youtube.com/watch?v=Fb8SE7MUeJA)
    - [El Día article](https://www.eldia.com/nota/2013-7-24-un-bandoneon-electronico-creado-en-la-ciudad-y-unico-en-el-mundo)
    - [Luthier documentary](https://www.youtube.com/watch?v=Ckur8W4RoJc)

## Bandoneon Electrónico - MIDI

Author
: Federico Fraysse

Year
: 2007 - 2018

Notes
: Actual bellow, it is not clear weather the push and pull intensity is measured.

License
: Unknown

References
: - [project presentation video](https://www.youtube.com/watch?v=qDdmXb_aneo)

## Bandoneon 2.0

Author
: Juan Ramos, Esteban Calcagno, Ramiro Vergara, Pablo Riera, Joaquín Rizza

Year
: 2018 - 2023

Notes
: Interdisciplinary academic project at the National University of Quilmes,
  Argentina, building an expressive, accessible electronic bandoneon with a
  measured-acoustics synthesis model. First prototype named "Alfa"; a successor
  named "Astor" was announced. Latest public output is the 2023 NIME paper.

License
: None known — academic research project.

References
:   - [Project page (Juan Ramos)](https://www.jaoramos.com.ar/bandoneon-2-0/)
    - [NIME 2022 paper (best paper award)](https://nime.pubpub.org/pub/31l4lgcd)
    - [NIME 2023 follow-up: embedded wavetable synthesizer](https://nime.org/proceedings/2023/nime2023_23.pdf)
    - [Computer Music Journal article](https://direct.mit.edu/comj/article-abstract/46/1-2/40/114878/An-Electronic-Bandoneon-with-a-Dynamic-Sound)
    - [UNQ science agency article](https://agencia.unq.edu.ar/?p=5437)

## Bandonberry

Author
: Jose Bentancour (Universidad de la República, Uruguay)

Year
: 2018 - 2019

Notes
: Fully 3D-printed MIDI bandoneon built around a Raspberry Pi as a learning
  simulator; 71 buttons via an SPI port expander, onboard I2S audio. No bellow
  sensing.

License
: MIT.

References
:   - [Project repository](https://github.com/jebentancour/Bandonberry)
    - [Thesis (Colibri, UdelaR)](https://www.colibri.udelar.edu.uy/jspui/handle/20.500.12008/23433)

## BandoMIDI

Author
: HLeBoucher

Year
: 2020

Notes
: Acoustic bandoneon retrofitted into a silent MIDI instrument using magnets and
  magnetic sensors read by an Arduino, with an Odroid C1+ for sound. Button
  presses only — no bellow sensing (the author notes this as a limitation).

License
: Open source (GitLab).

References
:   - [Hackaday.io project](https://hackaday.io/project/170753-bandomidi)
    - [Source repository](https://gitlab.com/HLeBoucher/bandomidi)
    - [Hackaday article](https://hackaday.com/2020/04/13/quieting-down-a-bandoneon-accordion-with-midi/)

## bandoMIneDonI

Author
: 3araht

Year
: 2021 - 2024

Notes
: MIDI keyboard kit with a bandoneon button layout and no bellow. Uses compact
  Kailh mid-height switches to reproduce the real inter-button spacing.

License
: None specified — all rights reserved.

References
:   - [Project repository](https://github.com/3araht/bandominedoni)
    - [Build video](https://www.youtube.com/watch?v=WzOsrSpjDgU)

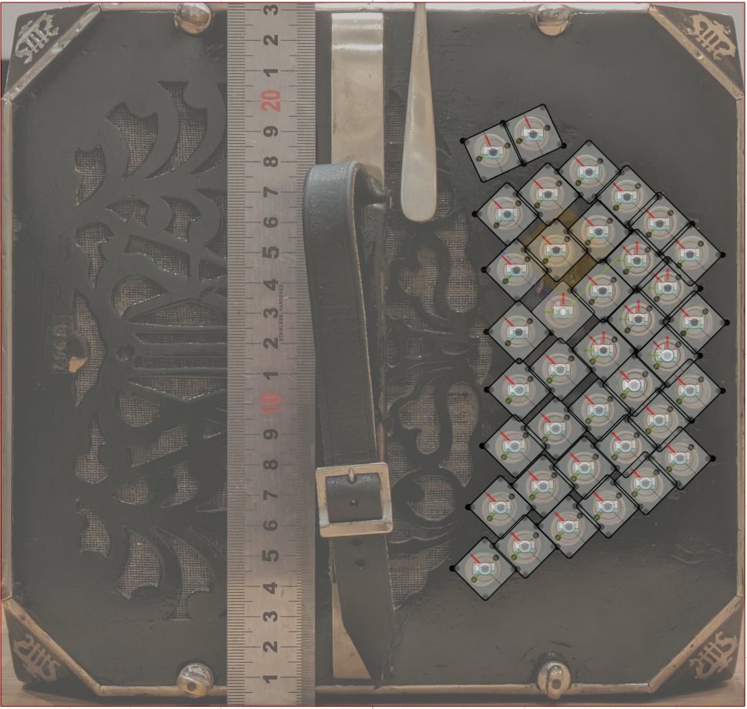
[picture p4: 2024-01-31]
images/Screenshot 2024-01-28 193750.png

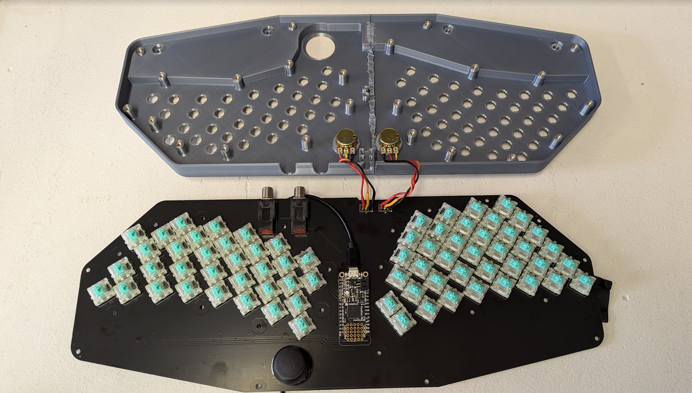
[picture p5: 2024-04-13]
images/Screenshot 2024-04-13 215116.png

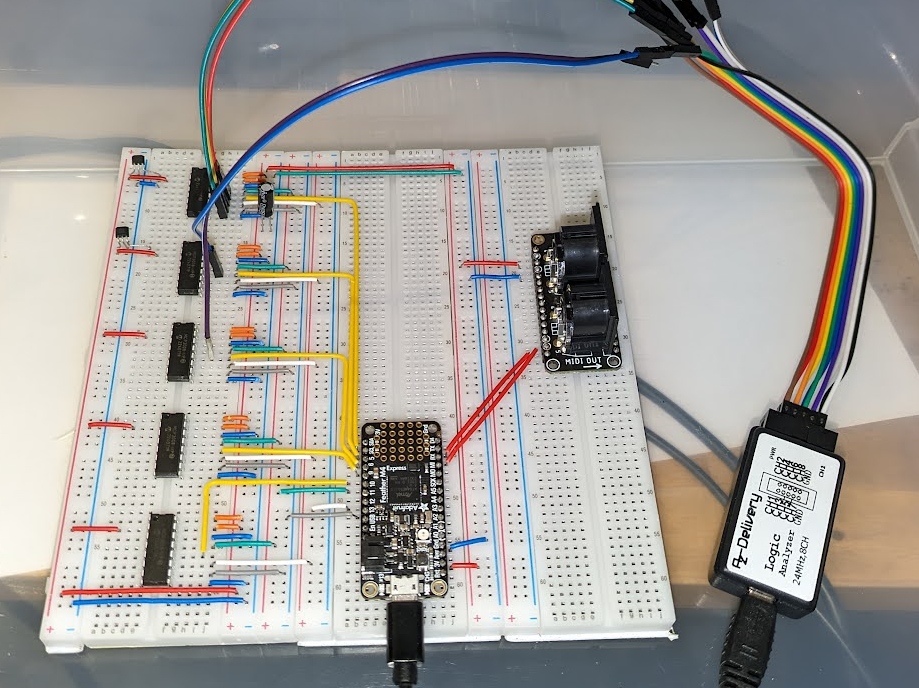
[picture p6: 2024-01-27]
images/Screenshot 2024-01-27 230825.png

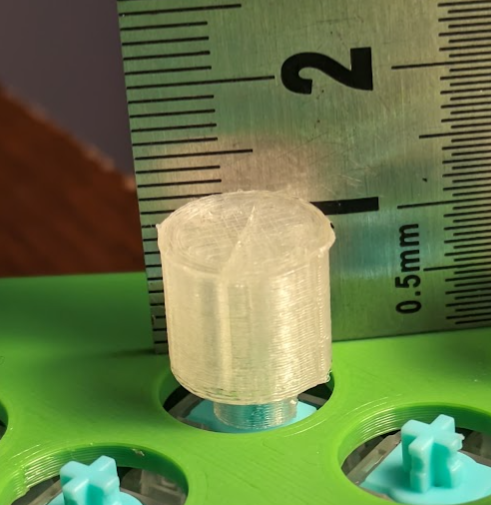
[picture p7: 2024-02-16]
images/Screenshot 2024-02-16 190515.png

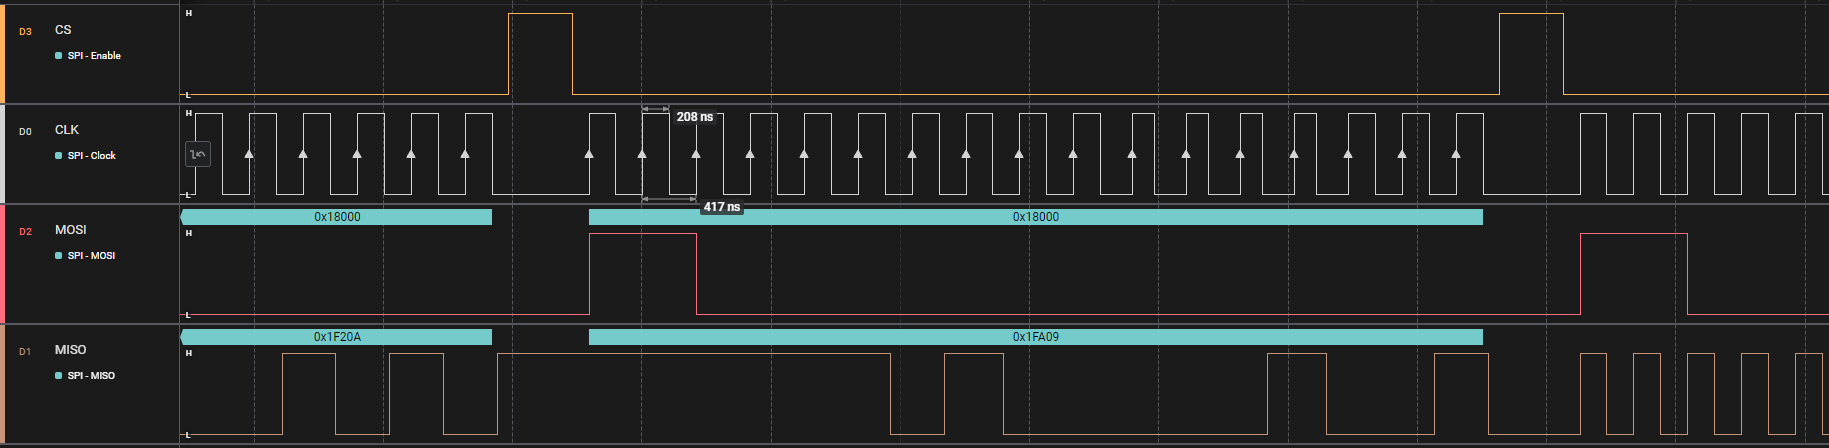
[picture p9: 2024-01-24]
images/Screenshot 2024-01-24 085408.png

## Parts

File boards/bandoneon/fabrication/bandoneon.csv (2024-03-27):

Comment | Designator | Footprint | LCSC Part #
1uF Unpolarized capacitor | C1,C2,C3,C4,C5,C6,C7,C8,C9 | C_0402_1005Metric | C52923
SS39ET Linear Hall-effect Sensor ICs | H1,H2,H3,H4,H5,H6,H7,H8,H9,H10,H11,H12,H13,H14,H15,H16,H17,H18,H19,H20,H21,H22,H23,H24,H25,H26,H27,H28,H29,H30,H31,H32,H33,H34,H35,H36,H37,H38,H39,H40,H41,H42,H43,H44,H45,H46,H47,H48,H49,H50,H51,H52,H53,H54,H55,H56,H57,H58,H59,H60,H61,H62,H63,H64,H65,H66,H67,H68,H69,H70,H71 | SOT-23_SS39ET | C126669
10K Resistor | R1 | R_0201_0603Metric | C25804
MCP3008 A/D Converter, 10-Bit, 8-Channel, SPI Interface , 2.7V-5.5V | U2,U3,U4,U5,U6,U7,U8,U9,U10 | SOIC-16_MCP3008T-I_SL | C1520159
SRV05-4 ESD Protection Diodes with Low Clamping Voltage, SOT-23-6 | U11,U12,U13 | SOT-23-6 | C2836319

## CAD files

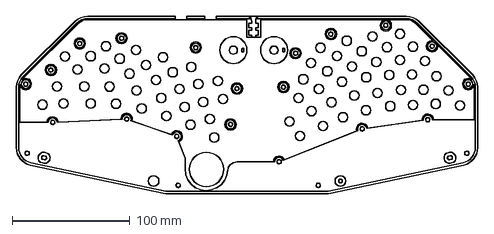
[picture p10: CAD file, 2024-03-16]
boards/bandoneon/carter.dxf
391.9 x 150.8 mm

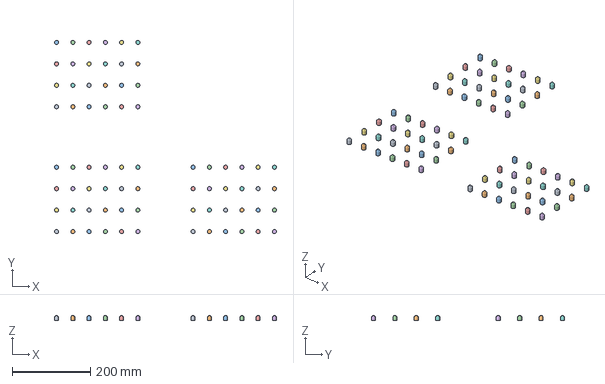
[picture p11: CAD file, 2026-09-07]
models/Bandolibre - Key - 72.3mf
569.0 x 495.7 x 14.0 mm

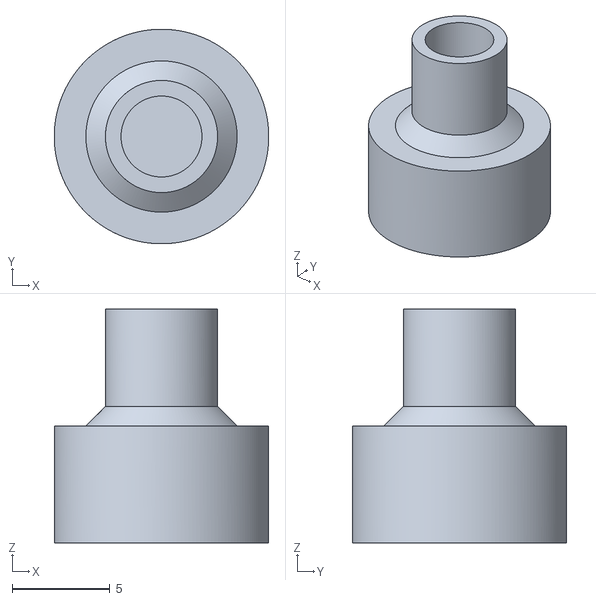
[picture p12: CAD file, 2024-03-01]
stl/caps/Cap-v2-cylinder-415.stl
11.0 x 11.0 x 12.0

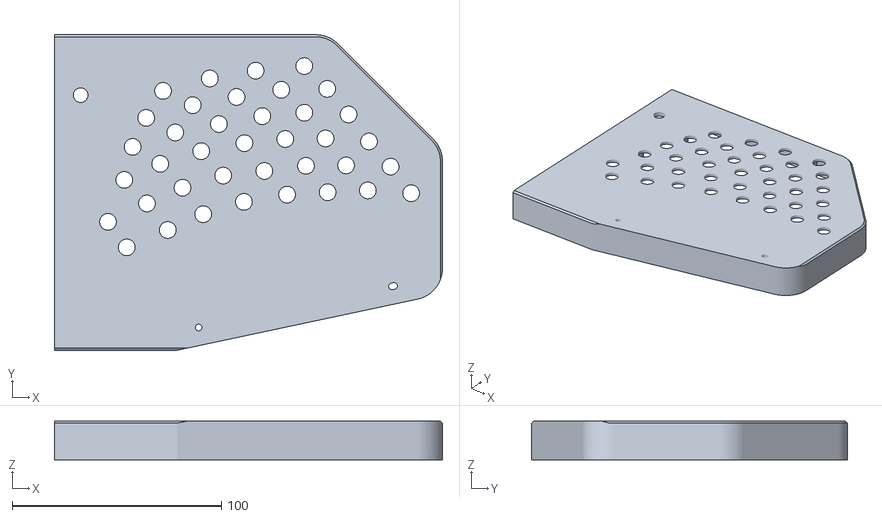
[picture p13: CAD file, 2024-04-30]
stl/Top R.stl
185.5 x 150.8 x 18.5

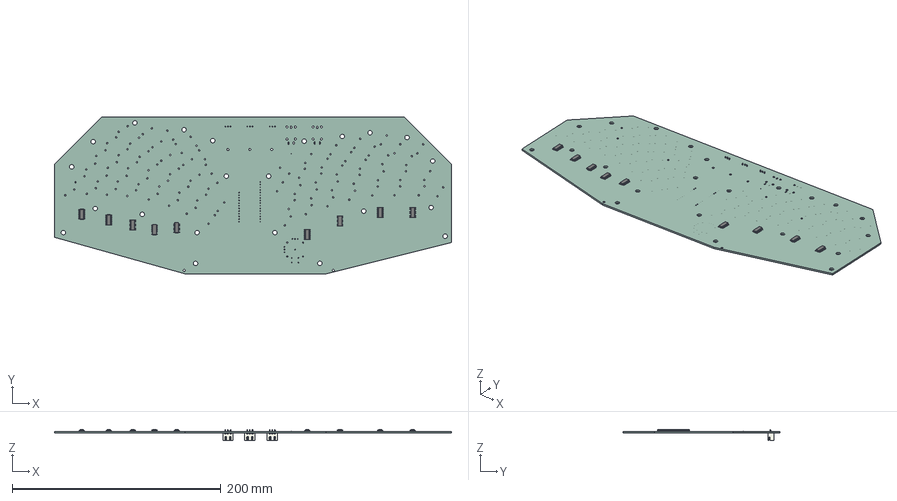
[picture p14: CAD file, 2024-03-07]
boards/bandoneon/bandoneon.step
380.0 x 150.0 x 10.4 mm
SOIC_16_39x99mm_P127mm x 9
R_0201_0603Metric
JST_B3B_XH_A x 3
bandoneon PCB

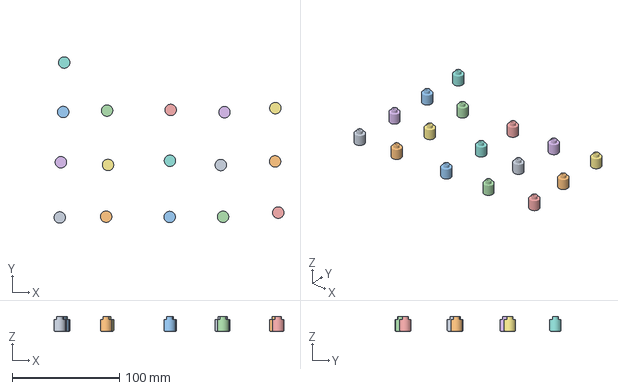
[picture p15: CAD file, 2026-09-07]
models/Bandolibre - Key - slice.3mf
214.0 x 154.8 x 14.0 mm

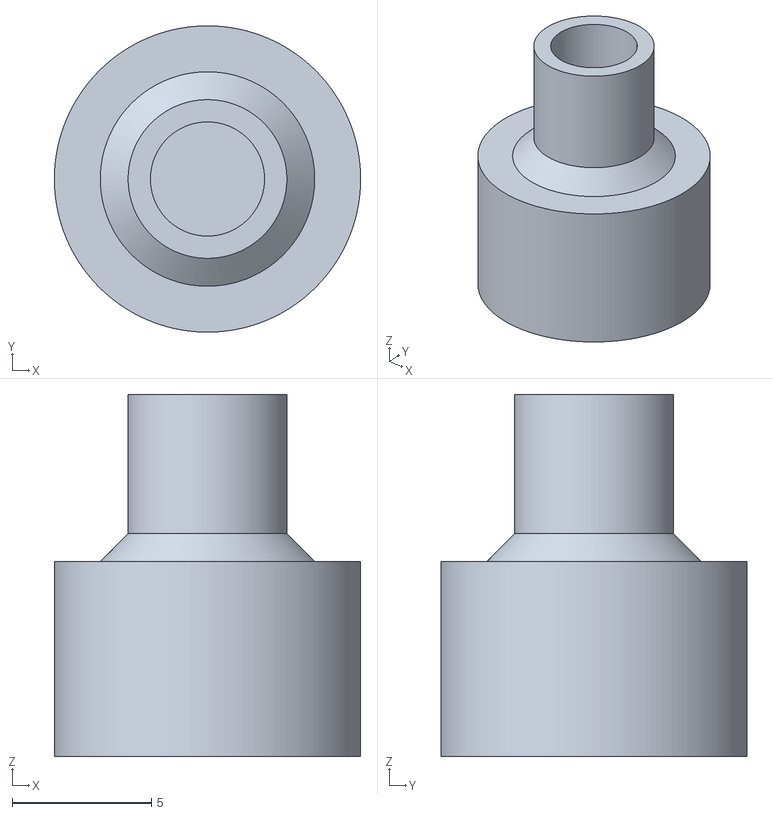
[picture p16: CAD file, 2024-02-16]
stl/caps/Cap2-v3.stl
11.0 x 11.0 x 13.0

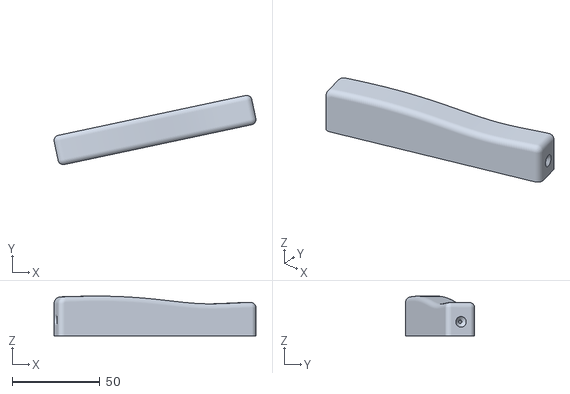
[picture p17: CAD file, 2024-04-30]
stl/Handle R.stl
114.9 x 39.4 x 22.6

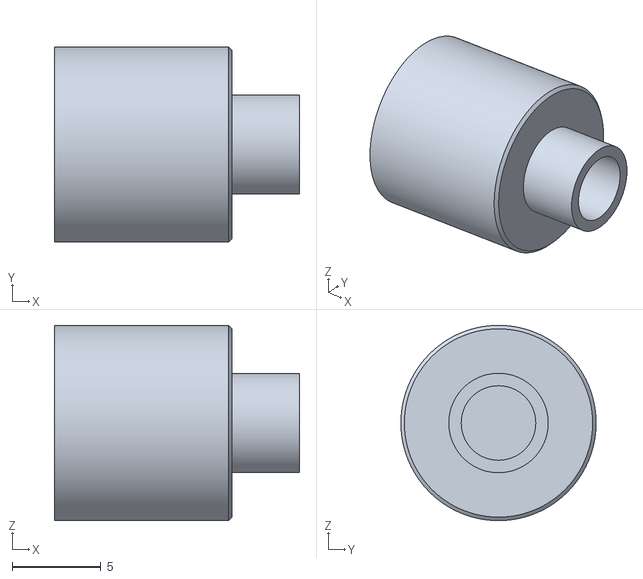
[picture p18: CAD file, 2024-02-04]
stl/caps/Cap-v2-cylinder-42.stl
13.8 x 11.0 x 11.0

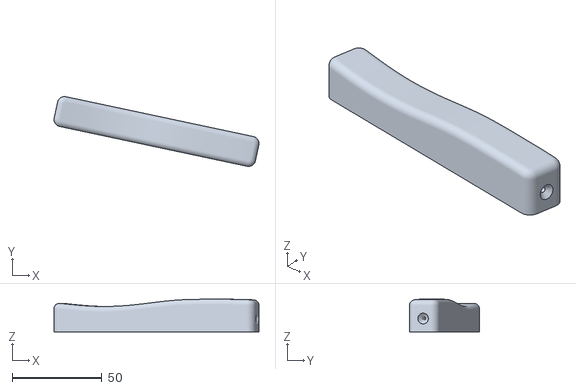
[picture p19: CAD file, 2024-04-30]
stl/Handle L.stl
114.5 x 39.0 x 18.2

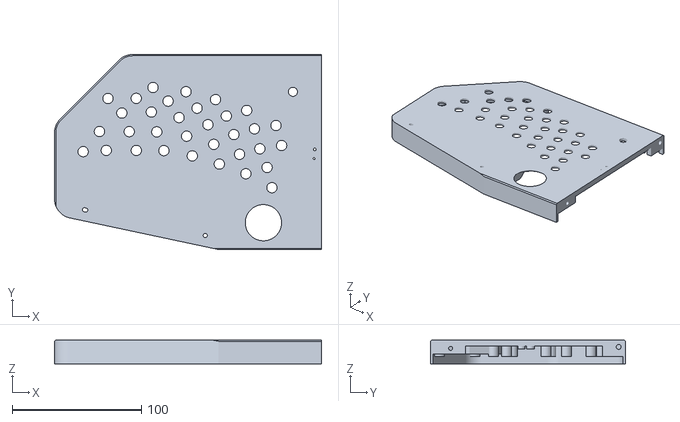
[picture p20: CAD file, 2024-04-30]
stl/Top L.stl
206.4 x 150.8 x 18.5

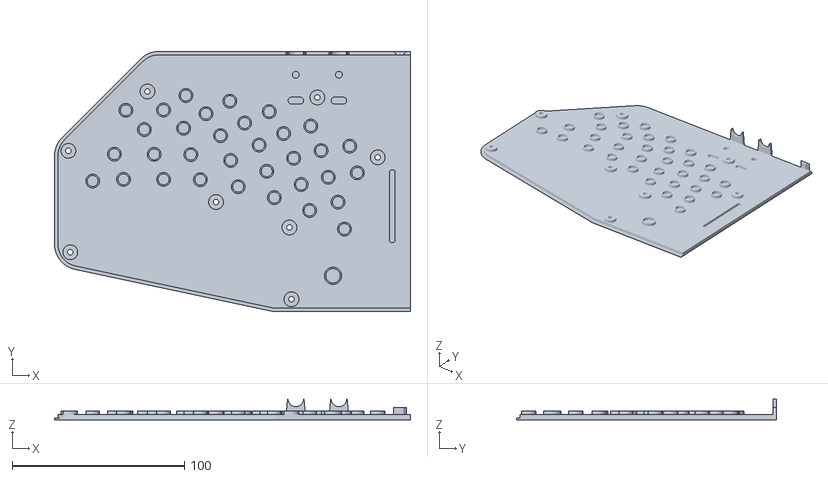
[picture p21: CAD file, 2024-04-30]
stl/Bottom L.stl
206.4 x 150.8 x 11.9

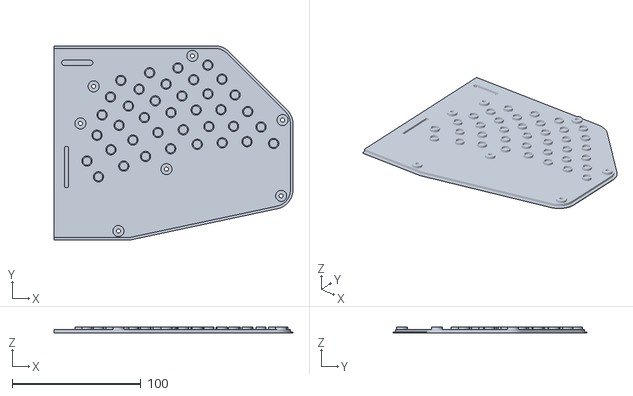
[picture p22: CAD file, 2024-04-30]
stl/Bottom R.stl
185.5 x 150.8 x 5.00

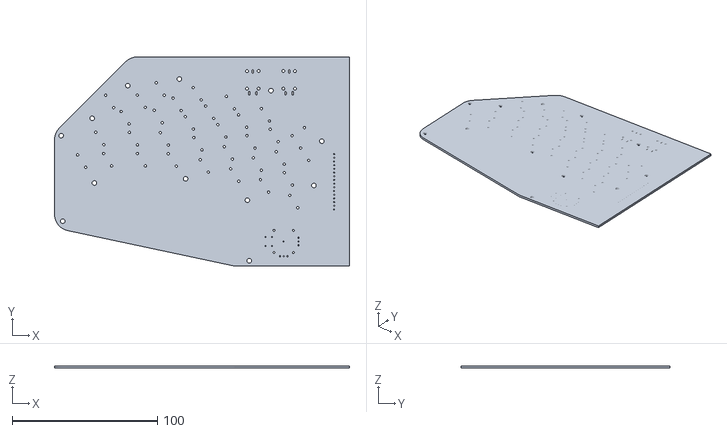
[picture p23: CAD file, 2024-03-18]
stl/PCB L.stl
202.9 x 143.8 x 1.60

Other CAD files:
stl/caps/Cap-v2-cylinder-45.stl
stl/caps/Cap-v1.stl
stl/PCB R.stl

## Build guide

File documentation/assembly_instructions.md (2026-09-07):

# Assembly instructions

The Bandolibre is meant to be built. It exists so that anyone, anywhere in the
world, can make one if they want to — this page walks you through everything it
takes.

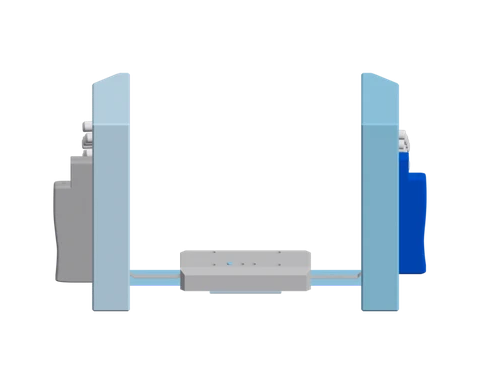
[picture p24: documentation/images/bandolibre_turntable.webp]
Bandolibre 3D model


<a href="https://cad.onshape.com/documents/313e70e978bf056a8dd7d76c/v/5c5fbc4088ac379c1bd1b53a/e/c6a89cb028bdc195ff70596f" target="_blank" rel="noopener">Open OnShape CAD model</a>

If you take that journey, don't be a stranger: let us know how it goes. We'd
love to hear about your progress, see your build, and learn from what you
discover along the way.

Don't worry if a picture doesn't quite match what you have in front of you: the
photos were taken in a slightly different assembly order. The text is the
reference.

## Bill of material: Tools and consumables

Everything you need, down to the last washer — because nothing ruins a build
like discovering, glue in hand, that the missing part ships from across the
planet.

### PCBs

| Part | Qty | Notes |
|---|-----|---|
| Main PCB | 1 | [EasyEDA design](../boards), [Production files](https://github.com/bandolibre/bandolibre.github.io/releases) |
| Left wing PCB | 1 | idem |
| Right wing PCB | 1 | idem |

The production files are designed for economical two-layer assembly and were
ordered from [JLCPCB](https://jlcpcb.com/). Costs can be cut further by
panelizing the designs into a single order.

### Glue

| Part | Qty | Notes |
|---|-----|---|
| Loctite 480 | 2 drops |  |

Bonds the magnet to the bellows blade spring. The magnet must not creep or
peel, or the Hall reading drifts; and the bond sits on a blade that flexes on
every stroke, so it must resist cyclic peel without cracking. 3M DP420 and
Loctite EA 9466 are alternatives; all three are toughened (rubber-modified)
structural adhesives that meet both.

### Bellows spring blade

| Part | Qty | Notes |
|---|-----|---|
| 65Mn spring steel strip, 1.2 × 40 × 300 mm | 1 | [supplier](https://fr.aliexpress.com/item/1005006952720032.html) |

The steel must be manganese-alloyed (65Mn) spring steel. Manganese gives it a
wide elastic domain, so the blade flexes far on every bellows stroke and returns
without taking a permanent set.

A 1.5 mm strip can be used instead for extra rigidity, but the bellows model
must be adjusted to match the stiffer blade.

### Magnets

| Part | Qty | Notes |
|---|-----|---|
| Permanent magnet, 14.5 × 6 × 2 mm | 2 | |

Bonded to the spring blade, the magnets move with it as it bends. A pair of
Hall-effect sensors reads the resulting field change to measure the blade's
flexion, which gives the force the player applies to the bellows.

### Cutting the blade springs

| Part | Qty | Notes |
|---|-----|---|
| Angle grinder | 1 | 125 mm |
| Norton Extreme steel/inox cutting disc | 1 | 125 × 1.6 mm, for an angle grinder |

Cuts the spring steel to length. The disc is thin enough to keep the kerf
narrow and the heat-affected zone small, so the steel keeps its temper at the
cut edge.

### Programming

| Part | Qty | Notes |
|---|-----|---|
| ST-LINK V3 MINIE | 1 | preferred; or ST-LINK V3 SET |
| [Tag-Connect TC2070-IDC-050](https://www.tag-connect.com) cable | 1 | 14 pogo pins that contact the board's footprint directly with no mating connector |
| USB-B to USB-A cable | 1 | Powers the main board while programming, and carries MIDI to the host |

Chosen against a J-Link because it is fast, cheap, and free of licence
restrictions. The ST-LINK V3 also exposes a USART, which is more robust than SWO
for logging and lets you send commands to the firmware during development. The
MINIE has all the features needed and is cheaper than the SET.

### Hexagonal keys

| Part | Qty | Notes |
|---|-----|---|
| Hexagonal Allen key H2 | 1 | |
| Hexagonal Allen key H2.5 | 1 | |
| Hexagonal Allen key H3 | 1 | |

All screws can be fastened with these three hexagonal Allen keys.

### PLA filament

| Part | Qty | Notes |
|---|-----|---|
| PLA for the body | 850 g | [Prusament PLA](https://www.prusa3d.com/category/prusament-pla/) |
| PETG for the keys | 60 g | [Prusament PETG](https://www.prusa3d.com/category/prusament-petg/) |

### Magnetic push buttons

| Part | Qty | Notes |
|---|-----|---|
| Hall-effect switches | 71 | [GATERON Low Profile Magnetic Jade HE](https://www.gateron.com/products/gateron-low-profile-magnetic-jade-switch?VariantsId=10872) |

You can opt for lighter 30±10gf springs selecting the non "Pro" version instead.

### Screws

| Part | Qty | Notes |
|---|-----|---|
| M4 × 30 socket head cap, stainless A2 | 4 | For the handles. [supplier](https://www.vis-express.fr/vis-metaux-inox-a2-chc-btr-cle-de-8-hc8-filetage-total-din-912-din-912-iso-4762/36756-927484-vis-metaux-inox-a2-chc-btr-cle-de-3-hc3-m4x40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)|
| M4 × 10 × 0.8 flat washer, stainless A2 | 4 | For the handles. [supplier](https://www.vis-express.fr/rondelle-plate-m-inox-a2-nfe-25513vs-nfe25513-grade-c/36925-940576-rondelle-plate-m4x10x08-m-inox-a2.html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)|
| M3 × 6 socket head cap, stainless A2 | 19 | For PCB fastening. [supplier](https://www.vis-express.fr/vis-metaux-inox-a2-chc-btr-cle-de-8-hc8-filetage-total-din-912-din-912-iso-4762/36726-2595617-vis-metaux-inox-a2-chc-btr-cle-de-25-hc25-m3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)|
| M3 × 8 socket head cap, stainless A2 | 11 | For the main board blade clamp. [supplier](https://www.vis-express.fr/vis-metaux-inox-a2-chc-btr-cle-de-8-hc8-filetage-total-din-912-din-912-iso-4762/36728-2610009-vis-metaux-inox-a2-chc-btr-cle-de-25-hc25-m3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) |
| M3 × 12 socket head cap, stainless A2 | 4 | For the wing blade clamp. [supplier](https://www.vis-express.fr/vis-metaux-inox-a2-chc-btr-cle-de-8-hc8-filetage-total-din-912-din-912-iso-4762/36731-2616466-vis-metaux-inox-a2-chc-btr-cle-de-25-hc25-m3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) |
| M3 × 18 socket head cap, stainless A2 | 4 | For the main board enclosure. [supplier](https://www.vis-express.fr/vis-metaux-inox-a2-chc-btr-cle-de-8-hc8-filetage-total-din-912-din-912-iso-4762/36734-2596394-vis-metaux-inox-a2-chc-btr-cle-de-25-hc25-m3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) |
| M3 × 5 flat head | 4 | For the handle straps. [supplier](https://fr.aliexpress.com/item/4001072025844.html) |

### Ribbon cable

| Part | Qty | Notes |
|---|-----|---|
| IDC ribbon cable, FC 1.27 mm, 12P (2×6), 10 cm | 2 | [supplier](https://fr.aliexpress.com/item/1005005058041580.html) |

Connects each wing to the main board. IDC ribbon cable is available everywhere,
and its 1.27 mm pitch keeps the connectors short. The 12 conductors give the SPI
link spare pins for interleaved grounds (lower noise) and extra VCC lines (less
voltage drop).

## Step-by-step assembly

### Print the parts

All the parts are printed with 15% density with no support.

The printable files are attached to the [GitHub releases](https://github.com/bandolibre/bandolibre.github.io/releases):

- `bandolibre-models-xxx.zip` — STEP files exported from the [Onshape model](https://cad.onshape.com/documents/313e70e978bf056a8dd7d76c/v/5c5fbc4088ac379c1bd1b53a/e/c6a89cb028bdc195ff70596f).
- `xxxx - slice.3mf` — PrusaSlicer projects that reference the models already arranged on the plate.

The projects print with "Complete individual objects" enabled, so each part is
finished before the next one starts. This avoids the travel moves back and forth
between parts, which makes the print faster and improves surface quality by
keeping oozing and stringing off the finished parts.

| Part | Count | Material | Print time | Filament |
|---|---|---|---|---|
| Central body | 1 | PLA | 1 h 32 min | 40 g |
| Central body blade clamp | 1 | PLA | 0 h 37 min | 24 g |
| Right keyboard body | 1 | PLA | 5 h 50 min | 223 g |
| Right keyboard cover | 1 | PLA | 1 h 21 min | 58 g |
| Left keyboard body | 1 | PLA | 5 h 50 min | 225 g |
| Left keyboard cover | 1 | PLA | 1 h 21 min | 58 g |
| Left and right handles | 1 | PLA | 1 h 24 min | 62 g |
| Set of 24 keys | 3 | PETG | 2 h 10 min | 18 g |
| **Total** | | | **24 h 25 min** | **744 g** |

Printing the keys

Printing the handles

### Cut the spring blade

With the angle grinder and slim cutting disc, cut the 65Mn spring steel strip to a 300 mm length.

Cutting the spring blade

Clamp the blade to a plank and keep a trickle of water running over the cut to
carry away the heat. If the steel gets too hot it re-hardens (quenches) at the
cut, losing the temper that gives it its elastic properties.

### Assemble keyboards

1. Push the keycaps onto the Gateron push-button switches.
2. Lay out the components on the table: place the keyboard PCB on the ESD mat, with the switches and keycaps within reach. Double-check the connectors are covered with a protection to avoid bending the pins.

Keyboard PCB on the ESD mat with switches and keycaps

3. Place the push buttons on the back of the board. Orient each one so the crystal aligns with the silkscreen drawing, so that the magnet sits in front of the sensor.

Push buttons placed on the back of the keyboard board

4. Hold the board by its component side and bring the printed keyboard body down onto it, guiding every switch through its matching hole in one motion. Seat the board fully so each switch clears its hole and the keycaps stand proud of the front face.

Sliding the keyboard body over the switches

### Assemble the main board

1. Set the clamp at the exact midpoint of the 300 mm blade, so both free ends flex symmetrically under the bellows load.
2. Fasten the clamp with 3 M3×8 screws.

Spring blade clamped at its midpoint

3. Find the magnet's blade-facing polarity: press a spare Gateron switch to bring its internal magnet down against the bottom of the housing, then check which face of a bellows magnet that bottom attracts. That face goes against the blade.
4. Fit the magnet guide, add a drop of glue to each seat, and set a magnet — attracted face down — into each. The guide aligns the magnet with its Hall sensor; the glue resists the cyclic peel of every bellows stroke.

Gluing the magnets into the guide on the blade

5. Once the glue has cured, lift the magnet guide off the magnets.
6. Set the main board onto its support.
7. Fasten it with 3 M3×6 screws.

Main board fastened to its support

### Fit the handle straps

Velcro tape makes cheap adjustable handle straps.

Velcro tape cut to length for a handle strap

1. Attach the velcro tape to each handle with two M3 × 5 flat head screws.

Velcro strap screwed onto a printed handle

2. Fix the left and right handles to their keyboards with two M4 × 30 socket
   head cap screws and washers each.

The handle position is adjustable; the median position matches the original
instrument.

### Fasten the wings to the blade

1. Bring each assembled keyboard up to the blade and slide the blade into its
   wing clamp. The blade should be a snug fit.
2. Fasten each clamp with two M3 × 12 screws.

Wing clamp

3. Connect the IDC ribbon cables, keeping them flat and untwisted. The
   connectors are not keyed: the cable is symmetrical, so either end fits either
   board.

Wing cable

### Program the main board

1. Connect the main board to a USB port with the USB-B to USB-A cable. An orange
   power indicator lights up. The ST-LINK V3 can power the board on its own only
   while the wings are disconnected; now that everything is wired, the board must
   be powered over USB.
2. Plug the TC2070-IDC-050 cable into the board footprint and into the ST-LINK
   V3, then connect the ST-LINK V3 to your workstation.

Main board connected to the ST-LINK V3 through the Tag-Connect cable
Main board connected to the ST-LINK V3 through the Tag-Connect cable

1. Flash the board following [Programming boards](programming_boards.md).
2. Unplug the ST-LINK V3, then the USB cable.

### Play and share

Your workstation should now detect the bandoneon as a USB MIDI device. Check
that every key and both bellows sensors behave as intended before fitting the
enclosure — everything is still accessible at this stage.

Then play it, and send us a picture of your build.

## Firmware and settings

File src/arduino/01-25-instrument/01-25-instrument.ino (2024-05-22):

#include <Adafruit_TinyUSB.h>
#include <Adafruit_NeoPixel.h>
#include <Arduino.h>
#include <MIDI.h>

#include <array>
#include <cassert>
#include <vector>

constexpr size_t kNotesCount = 12;
constexpr char const *kNotesNames[kNotesCount] = {
    "C",     "C#/Db", "D",     "D#/Eb", "E",     "F",
    "F#/Gb", "G",     "G#/Ab", "A",     "A#/Bb", "B",
};

// Returns the MIDI note index for a given not and octave.
enum { C, Cd, D, Dd, E, F, Fd, G, Gd, A, Ad, B };
constexpr uint8_t n(int note, int octave) {
  return (octave + 1) * kNotesCount + static_cast<int>(note);
}

// Maps measure position to a MIDI note index.
// 0: close/push, 1: open/pull
constexpr uint8_t keyboard_mapping[2][72] = {
    {
        /*00*/ 0,        n(Fd, 4), n(A, 6),  n(Ad, 4), n(A, 5),
        /*05*/ n(E, 2),  n(G, 3),  n(Ad, 2), n(Gd, 3), n(G, 4),
        /*10*/ n(E, 4),  n(G, 6),  n(B, 4),  n(E, 6),  n(A, 2),
        /*15*/ n(A, 3),  n(C, 4),  n(Cd, 2), n(A, 3),  n(F, 5),
        /*20*/ n(Gd, 4), n(E, 5),  n(F, 6),  n(E, 3),  n(Gd, 4),
        /*25*/ n(D, 4),  n(Dd, 4), n(Ad, 3), n(C, 4),  n(G, 4),
        /*30*/ n(B, 5),  n(Dd, 6), n(D, 2),  n(G, 2),  n(E, 4),
        /*35*/ n(C, 3),  n(B, 3),  n(Cd, 4), n(Cd, 5), n(Fd, 6),
        /*40*/ n(D, 6),  n(G, 2),  n(Ad, 3), n(F, 3),  n(Fd, 3),
        /*45*/ n(F, 4),  n(Fd, 5), n(Gd, 5), n(C, 6),  n(G, 5),
        /*50*/ n(E, 3),  n(B, 3),  n(Dd, 3), n(B, 2),  n(Dd, 4),
        /*55*/ n(A, 4),  n(Gd, 6), n(C, 5),  n(Cd, 6), n(Fd, 4),
        /*60*/ n(Cd, 4), n(Cd, 3), n(Fd, 2), n(D, 4),  n(E, 5),
        /*65*/ n(Ad, 5), n(D, 5),  n(Dd, 5), n(D, 3),  n(B, 4),
        /*70*/ n(F, 4),  n(F, 2),
    },
    {
        /*00*/ 0,        n(E, 4),  n(B, 6),  n(Ad, 5), n(Gd, 5),
        /*05*/ n(D, 2),  n(A, 3),  n(Ad, 2), n(Cd, 4), n(Gd, 4),
        /*10*/ n(Ad, 4), n(A, 6),  n(A, 4),  n(Cd, 6), n(E, 3),
        /*15*/ n(B, 3),  n(Dd, 3), n(Dd, 2), n(A, 3),  n(F, 5),
        /*20*/ n(G, 4),  n(D, 5),  n(F, 6),  n(B, 2),  n(A, 4),
        /*25*/ n(E, 4),  n(F, 3),  n(Ad, 3), n(Cd, 4), n(Fd, 4),
        /*30*/ n(A, 5),  n(Dd, 6), n(E, 2),  n(Gd, 2), n(Fd, 4),
        /*35*/ n(Ad, 3), n(B, 3),  n(D, 4),  n(B, 4),  n(G, 6),
        /*40*/ n(D, 6),  n(D, 3),  n(G, 3),  n(Fd, 3), n(G, 2),
        /*45*/ n(F, 4),  n(Cd, 5), n(Fd, 5), n(E, 6),  n(E, 5),
        /*50*/ n(Gd, 3), n(C, 4),  n(Cd, 3), n(Fd, 2), n(Dd, 4),
        /*55*/ n(Gd, 4), n(Gd, 6), n(C, 6),  n(B, 5),  n(G, 4),
        /*60*/ n(D, 4),  n(F, 4),  n(F, 2),  n(C, 4),  n(Dd, 5),
        /*65*/ n(Fd, 6), n(C, 5),  n(G, 5),  n(A, 2),  n(Dd, 4),
        /*70*/ n(C, 3),  n(C, 2),
    }};

// 1 for the right hand and 0 for the left hand.
constexpr uint8_t keyboard_channel[72] = {
    /*00*/ 0, 1, 1, 1, 1,
    /*05*/ 0, 0, 0, 0, 0,
    /*10*/ 1, 1, 1, 1, 0,
    /*15*/ 0, 0, 0, 1, 1,
    /*20*/ 1, 1, 1, 0, 0,
    /*25*/ 0, 0, 1, 1, 1,
    /*30*/ 1, 1, 0, 0, 0,
    /*35*/ 0, 1, 1, 1, 1,
    /*40*/ 1, 0, 0, 0, 0,
    /*45*/ 1, 1, 1, 1, 1,
    /*50*/ 0, 0, 0, 0, 1,
    /*55*/ 1, 1, 1, 1, 0,
    /*60*/ 0, 0, 0, 1, 1,
    /*65*/ 1, 1, 1, 0, 0,
    /*70*/ 0, 0};

// USB MIDI object
Adafruit_USBD_MIDI usb_midi;
Adafruit_NeoPixel pixels(1, 8);

// Create a new instance of the Arduino MIDI Library,
// and attach usb_midi as the transport.
MIDI_CREATE_INSTANCE(Adafruit_USBD_MIDI, usb_midi, MIDI);

#define digitalPinToBitShift(P) (g_APinDescription[P].ulPin)

// This is assuing the clear register is contiguous with the set.
// Static assertion complains when testing the pointers.
#define SET_PORT_BIT(P, mask, value)       \
  do {                                     \
    *(&REG_PORT_OUTCLR##P + value) = mask; \
  } while (0)

#define PROFILE(x)                    \
  {                                   \
    DWT->CYCCNT = 0;                  \
    x;                                \
    const uint32_t end = DWT->CYCCNT; \
    Serial.print(#x);                 \
    Serial.print(" took ");           \
    Serial.print(end);                \
    Serial.println(" cycles");        \
  }

#undef assert
#define assert(x)                      \
  do {                                 \
    if (!(x)) {                        \
      Serial.println();                \
      Serial.print("Assert failed: "); \
      Serial.println(#x);              \
      Serial.print(__FILE__);          \
      Serial.print(":");               \
      Serial.println(__LINE__);        \
    }                                  \
  } while (0);

template <typename... A>
struct TT {};
template <size_t N>
class SPIArray {
 private:
  enum Mode { IDLE_LOW, IDEL_HIGH };
  using PadValue = uint32_t;

  static_assert(
      sizeof(*portOutputRegister(digitalPinToPort(0))) == sizeof(PadValue),
      "the pad size looks incorrect. Please fix to match your architecture.");

  // User provided configuration.
  const uint8_t clk_;
  const uint8_t mosi_;
  const std::array<uint8_t, N> miso_;
  const uint8_t cs_;

  // Hardware mapping.
  PadValue cs_mask_, clk_mask_, mosi_mask_;
  std::array<uint32_t, N> miso_shifts_;

 public:
  uint32_t half_period_cyc_;
  SPIArray(uint8_t clk, uint8_t mosi, std::array<uint8_t, N> miso, uint8_t cs)
      : clk_(clk), mosi_(mosi), miso_(std::move(miso)), cs_(cs) {
    // Asserts that all specified pins are in the same port.
    clk_mask_ = digitalPinToBitMask(clk_);
    mosi_mask_ = digitalPinToBitMask(mosi_);
    for (int i = 0; i < N; i++) {
      miso_shifts_[i] = digitalPinToBitShift(miso[i]);
    }
    cs_mask_ = digitalPinToBitMask(cs_);
  }

  void begin() const {
    pinMode(cs_, OUTPUT);
    digitalWrite(cs_, HIGH);

    pinMode(clk_, OUTPUT);
    // Only Spi mode 0 is supported: idle low on mode 0 and 1
    digitalWrite(clk_, LOW);

    pinMode(mosi_, OUTPUT);
    digitalWrite(mosi_, HIGH);

    for (auto pin : miso_) {
      pinMode(pin, INPUT);
    }
  }

  int size() const { return miso_.size(); }
  inline void select(bool value) const { SET_PORT_BIT(0, cs_mask_, !value); }

  inline void transfer(const uint32_t wbuf, const uint32_t lsb_bits_to_transmit,
                       uint32_t *rbuf) const {  // Use std::span<uint32_t, N>
                                                // when available.
    for (int8_t shift = lsb_bits_to_transmit - 1; shift >= 0; shift--) {
      const bool mosi_value = (wbuf >> shift) & 0x1;
      SET_PORT_BIT(0, mosi_mask_, mosi_value);

      REG_PORT_OUTSET0 = clk_mask_;

      __NOP();
      __NOP();
      __NOP();
      __NOP();
      __NOP();
      const uint32_t in = REG_PORT_IN0;
      int i = 0;
      for (; i < N / 2; i++) {
        const bool bit = (in >> miso_shifts_[i]) & 0x1;
        rbuf[i] = (rbuf[i] << 1) | bit;
      }

      REG_PORT_OUTCLR0 = clk_mask_;

      for (; i < N; i++) {
        const bool bit = (in >> miso_shifts_[i]) & 0x1;
        rbuf[i] = (rbuf[i] << 1) | bit;
      }
    }
  }
};

template <size_t N>
class MCP3008Array {
  SPIArray<N> spi_array_;

 public:
  typedef std::array<uint32_t, N * 8> Values;

  // Use digital pin index as visible on the Feather pinout.
  MCP3008Array(uint8_t clk, uint8_t mosi, std::array<uint8_t, N> miso,
               uint8_t cs)
      : spi_array_(clk, mosi, miso, cs) {}

  void begin() const { spi_array_.begin(); }
  // Returns the measures for all channels of all ADCs.
  // values[channel_idx * N + adc_idx]
  void read(Values &values) const {
    for (uint8_t channel = 0; channel < 8; channel++) {
      spi_array_.select(true);
      const uint32_t write = 0x18000 | (channel << 12);
      spi_array_.transfer(write, 17, &values[channel * N]);
      spi_array_.select(false);
    }
    for (auto &v : values) {
      v &= 0x3ff;
    }
  }
};

MCP3008Array<9> adc_array(13, 12, {10, 9, 6, 5, 22, 21, 4, 25, 19}, 11);
uint32_t count = 0;

void setup() {
  usb_midi.setStringDescriptor("Bandoneon");

  // Initialize MIDI, and listen to all MIDI channels
  // This will also call usb_midi's begin()
  MIDI.begin(MIDI_CHANNEL_OMNI);

  // Enable logging through the serial port.
  Serial.begin(115200);
  adc_array.begin();

  // Wait until device mounted
  while (!TinyUSBDevice.mounted()) delay(1);

  // Light the pixel.
  pixels.begin();  
  pixels.show(); 
  pixels.clear();  
  pixels.setPixelColor(0, pixels.Color(0,1,2));
  pixels.show(); 
}

class Heartbit {
  uint32_t last_display_ms_;
  uint32_t tick_count_;
  static constexpr uint32_t kHeartbitPeriodMs = 10000;

 public:
  Heartbit() : last_display_ms_(millis()), tick_count_(0) {}
  bool tick() {
    tick_count_++;
    uint32_t delay = millis() - last_display_ms_;
    if (delay > kHeartbitPeriodMs) {
      last_display_ms_ += kHeartbitPeriodMs;
      Serial.print("Heartbit: scan frequency is ");
      Serial.print(tick_count_ * 1000 / delay);
      Serial.println(" Hz");
      tick_count_ = 0;
      return true;
    }
    return false;
  }
};

class Devices {
 public:
  struct Pinout {
    uint32_t p1_analog;
    uint32_t p2_analog;
    uint32_t expression_pedal_analog;
    uint32_t joy_x_analog;
    uint32_t joy_y_analog;
    uint32_t joy_bt_digital;
    uint32_t sustain_pedal_digital;
  } pinout_;

  struct Value {
    uint32_t p1;
    uint32_t p2;
    uint32_t expression_pedal;
    uint32_t joy_x;
    uint32_t joy_y;
    bool joy_bt;
    bool sustain_pedal;

    void print() {
      Serial.print("p1: ");
      Serial.print(p1);
      Serial.print(" p2: ");
      Serial.print(p2);
      Serial.print(" exp: ");
      Serial.print(expression_pedal);
      Serial.print(" sus: ");
      Serial.print(sustain_pedal);
      Serial.println();
      Serial.print("joy_x: ");
      Serial.print(joy_x);
      Serial.print(" y: ");
      Serial.print(joy_y);
      Serial.print(" bt: ");
      Serial.print(joy_bt);
      Serial.println();
    }
  };

  Devices(Pinout pinout) : pinout_(pinout) {
    pinMode(pinout_.p1_analog, INPUT);
    pinMode(pinout_.p2_analog, INPUT);
    pinMode(pinout_.expression_pedal_analog, INPUT);
    pinMode(pinout_.joy_x_analog, INPUT);
    pinMode(pinout_.joy_y_analog, INPUT);
    pinMode(pinout_.sustain_pedal_digital, INPUT_PULLUP);
    pinMode(pinout_.joy_bt_digital, INPUT_PULLUP);
  }

  void read(Value &value) {
    value.p1 = analogRead(pinout_.p1_analog);
    value.p2 = analogRead(pinout_.p2_analog);
    value.expression_pedal = analogRead(pinout_.expression_pedal_analog);
    value.joy_x = analogRead(pinout_.joy_x_analog);
    value.joy_y = analogRead(pinout_.joy_y_analog);
    value.joy_bt = digitalRead(pinout_.joy_bt_digital);
    value.sustain_pedal = digitalRead(pinout_.sustain_pedal_digital);
  }
};

Devices devices({
    .p1_analog = A1,
    .p2_analog = A0,
    .expression_pedal_analog = A2,
    .joy_x_analog = A3,
    .joy_y_analog = A4,
    .joy_bt_digital = 1,
    .sustain_pedal_digital = 0,
});

struct HysteresisFilter {
  const int32_t gap = 5;
  bool increasing = true;
  int32_t previous_value = 0;

  uint32_t apply(int32_t new_value) {
    if (increasing) {
      if (new_value > previous_value) {
        previous_value = new_value;
      } else if (new_value < previous_value - gap) {
        increasing = false;
        previous_value = new_value;
      }
    } else {
      if (new_value < previous_value) {
        previous_value = new_value;

      } else if (new_value > previous_value - gap) {
        increasing = true;
        previous_value = new_value;
      }
    }
    return previous_value;
  }
};

struct AxisMapper {
  int32_t min;
  int32_t max;

  int32_t out_min;
  int32_t out_max;

  int32_t remap(int32_t value) const {
    if (value < min) {
      return out_min;
    }
    if (value < max) {
      return out_min + (value - min) * (out_max - out_min) / (max - min);
    }
    return out_max;
  }
};

struct JoystickAxisMapper {
  uint32_t min;
  uint32_t max;
  // Central deadzone, inclusive
  uint32_t dead_min;
  uint32_t dead_max;

  uint32_t out_min;
  uint32_t out_max;
  uint32_t out_center;

  uint32_t remap(uint32_t value) const {
    if (value < min) {
      return out_min;
    }
    if (value < dead_min) {
      return out_center -
             (dead_min - value) * (out_center - out_min) / (dead_min - min);
    }
    if (value <= dead_max) {
      return out_center;
    }
    if (value < max) {
      return out_center +
             (value - dead_max) * (out_max - out_center) / (max - dead_max);
    }
    return out_max;
  }
};

constexpr AxisMapper expression_mapper{
    .min = 92,
    .max = 515,
    .out_min = 0x7f,
    .out_max = 0x0,
};

// proto 2: min=2 max=1021
constexpr AxisMapper p1_mapper{
    .min = 3 + 1,
    .max = 1021 - 1,
    .out_min = 0x7f,
    .out_max = 0x0,
};

// proto 2: min=2 max=1021
constexpr AxisMapper p2_mapper{
    .min = 3 + 1,
    .max = 1021 - 1,
    .out_min = 0x7f, 
    .out_max = 0x0,
};

constexpr JoystickAxisMapper y_axis_mapper{.min = 3 + 1,
                                           .max = 1023 - 1,
                                           .dead_min = 515 - 2,
                                           .dead_max = 515 + 2,
                                           .out_min = 0x0,
                                           .out_max = 0x7f,
                                           .out_center = 0x40};

constexpr bool kPrintKey = false;
constexpr bool kPrintMidiEvents = false;

// Low pass filter on the derivate of the signal.
// The current derivate is merged in the previous one with a factor.
// 1 ignore the past, and 0 ignore the present.
constexpr float kDecayFactor = 0.25;
// Velocity profile.
constexpr float kMinVelocity = 0.35;
constexpr float kMaxVelocity = 12.47;

// Measure above which one a key is considered pressed.
constexpr int32_t kPressThreshold = 600;
constexpr int32_t kReleaseThreshold = 580;

constexpr int32_t kMeasuresSize = 16;

constexpr int32_t kMidiChannel = 1;

// Holds reading for each key, with some history.
decltype(adc_array)::Values measures[kMeasuresSize] = {};
// Time just before staring the corresponding reading.
int32_t measures_us[kMeasuresSize] = {};

std::array<bool, measures[0].size()> isPressed{};

template <size_t N>
void printKeyboardState(const std::array<uint32_t, N> &values) {
  Serial.print("=== Keyboard state ===");
  for (uint32_t i = 0; i < values.size(); i++) {
    if (i % (N / 8) == 0) Serial.println();
    size_t len = Serial.print(values[i] > 600 ? 1 : 0);
    for (int c = max(0, 5 - len); c--;) Serial.print(' ');
    Serial.print(',');
  }
  Serial.println();
}

void printNoteName(uint8_t midi_code) {
  const int note_idx = midi_code % kNotesCount;
  const int octave = midi_code / kNotesCount - 1;
  Serial.print(kNotesNames[note_idx]);
  Serial.print(octave);
}

void loop() {
  Heartbit heartbit;

  // Initialises all the measure histroy from an initial reading.
  for (uint32_t t = 1; t < kMeasuresSize; t++) {
    measures_us[t] = micros();
    adc_array.read(measures[t]);
  }

  uint32_t t1_id = 0;
  uint32_t previous_bend = 0x40;  // center
  uint32_t previous_sustain = 0;
  uint32_t previous_expression = 0;
  uint32_t previous_p1 = 0;
  uint32_t previous_p2 = 0;
  HysteresisFilter p1_filter, p2_filter;

  for (;;) {
    // Capture time and measures.
    auto t1 = measures_us[t1_id] = micros();
    auto &measures_t1 = measures[t1_id];
    adc_array.read(measures_t1);

    // Use the oldest available record as reference point.
    auto t0_id = t1_id = (t1_id + 1) % kMeasuresSize;

    const auto t0 = measures_us[t0_id];
    const auto &measures_t0 = measures[t0_id];

    // The oldest value is also the next to write to.
    t1_id = t0_id;

    for (int i = 0; i < measures_t1.size(); i++) {
      if (measures_t1[i] > kPressThreshold && !isPressed[i]) {
        isPressed[i] = true;

        float derivate = 1000.f * (measures_t1[i] - measures_t0[i]) / (t1 - t0);
        // Clamp the derivative.
        derivate = min(max(derivate, min(kMinVelocity, kMaxVelocity)),
                       max(kMinVelocity, kMaxVelocity));
        // Compute the velocity from 1 to 127.
        const int32_t velocity = 1. + (derivate - kMinVelocity) /
                                          (kMaxVelocity - kMinVelocity) * 126.;

        // Send Note On for current position at full velocity (127) on
        // channel 1.
        uint8_t channel = kMidiChannel + keyboard_channel[i];
        MIDI.sendNoteOn(keyboard_mapping[1][i], velocity, channel);
        if (kPrintKey) {
          Serial.print(">>> Key ");
          Serial.print(i);
          Serial.print(" mapping: ");
          Serial.print(keyboard_mapping[1][i]);
          Serial.print("=");
          printNoteName(keyboard_mapping[1][i]);
          Serial.print(" channel: ");
          Serial.print(channel);
          Serial.print(" derivate: ");
          Serial.print(derivate);
          Serial.print(" velocity: ");
          Serial.print(velocity);
          Serial.print(", measures: ");
          Serial.print(measures_t1[i]);
          Serial.print(" -> ");
          Serial.print(measures_t0[i]);
          Serial.print(" delta:");
          Serial.print((static_cast<float>(measures_t1[i]) - measures_t0[i]));
          Serial.println();
        }
      } else if (measures_t1[i] < kReleaseThreshold && isPressed[i]) {
        isPressed[i] = false;

        // Send Note Off for previous note.
        MIDI.sendNoteOff(keyboard_mapping[1][i], 0,
                         kMidiChannel + keyboard_channel[i]);
        if (kPrintKey) {
          Serial.print(">>> Key ");
          Serial.print(i);
          Serial.println(" released.");
        }
      }
    }

    Devices::Value device_values;
    devices.read(device_values);

    const uint32_t bend = y_axis_mapper.remap(device_values.joy_y);
    if (bend != previous_bend) {
      MIDI.send(midi::MidiType::PitchBend, 0, bend, kMidiChannel);
      MIDI.send(midi::MidiType::PitchBend, 0, bend, kMidiChannel + 1);
      previous_bend = bend;
      if (kPrintMidiEvents) {
        Serial.print("joy: ");
        Serial.print(device_values.joy_y);
        Serial.print(" bend:");
        Serial.println(bend);
      }
    }

    const uint32_t expression =
        expression_mapper.remap(device_values.expression_pedal);
    if (expression != previous_expression) {
      MIDI.send(midi::MidiType::ControlChange, 1, expression, kMidiChannel);
      MIDI.send(midi::MidiType::ControlChange, 1, expression, kMidiChannel+1);
      previous_expression = expression;
    }

    if (device_values.sustain_pedal != previous_sustain) {
      MIDI.send(midi::MidiType::ControlChange, 64,
                device_values.sustain_pedal ? 0 : 127, kMidiChannel);
      MIDI.send(midi::MidiType::ControlChange, 64,
                device_values.sustain_pedal ? 0 : 127, kMidiChannel + 1);
      previous_sustain = device_values.sustain_pedal;
    }

    const uint32_t p1 = p1_mapper.remap(p1_filter.apply(device_values.p1));
    if (p1 != previous_p1) {      
      MIDI.send(midi::MidiType::ControlChange, 12, p1, kMidiChannel);
      MIDI.send(midi::MidiType::ControlChange, 12, p1, kMidiChannel + 1);
      previous_p1 = p1;
      if (kPrintMidiEvents) {
        Serial.print("device_values.p1: ");
        Serial.print(device_values.p1);
        Serial.print(" p1: ");
        Serial.print(p1);
        Serial.println();
      }
    }

    const uint32_t p2 = p2_mapper.remap(p2_filter.apply(device_values.p2));
    if (p2 != previous_p2) {
      MIDI.send(midi::MidiType::ControlChange, 13, p2, kMidiChannel);
      MIDI.send(midi::MidiType::ControlChange, 13, p2, kMidiChannel + 1);
      previous_p2 = p2;
      if (kPrintMidiEvents) {
        Serial.print("device_values.p2: ");
        Serial.print(device_values.p2);
        Serial.print(" p2: ");
        Serial.print(p2);
        Serial.println();
      }
    }
    // Let the USB stack opeate if needed.
    yield();
    if (heartbit.tick()) {
      //device_values.print();
      // printKeyboardState(measures_t1);
    }
  }
}

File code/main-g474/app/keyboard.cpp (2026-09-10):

#include <stdio.h>
#include <string.h>

extern "C" {
#include "main.h"
#include "spi_link.h"
#include "hall_report.h"
#include "keyboard_layout.h"
#include "bellow.h"
#include "buttons.h"
#include "console.h"
#include "properties.h"
#include "report.h"
#include "usb_app.h"
#include "keyboard.h"

/* SPI handles for the two wing links, defined by the CubeMX-generated main.c. */
extern SPI_HandleTypeDef hspi1;
extern SPI_HandleTypeDef hspi2;

/* The frame's per-key payload is exactly what the shared hall report renders. */
_Static_assert(SPI_LINK_NUM_KEYS == HALL_REPORT_NUM_KEYS,
               "SPI frame key count must match the shared hall report layout");

/* Press/release hysteresis: a hall reading falls as a key is pressed and rises
 * back as it is released. key_release > key_press gives a dead band so a key
 * resting near the trip point doesn't chatter. See g_properties (properties.h). */





// Lock free producer consumer queue where only the latest
// produced buffer is made available to the consumer.
class TripleBuffer {

  struct Buffer {
    bool to_be_consumed = 0;
    uint16_t data[SPI_LINK_FRAME_WORDS] {};
  };

  Buffer buffers[3] {};

  // Invarient: At any time those 3 variables contains 0, 1 and 2 in any order.
  uint8_t producer_idx = 0;
  uint8_t shared_idx = 1;
  uint8_t consumer_idx = 2;

  public:
    // Make the current producer available to the consumer.
    void release_producer_buffer() {
      // The producer buffer is assumed to be valid.
      buffers[producer_idx].to_be_consumed = true;
      __atomic_exchange(&shared_idx, &producer_idx, &producer_idx, __ATOMIC_RELEASE);
    };

    bool acquire_consumer_buffer() {
      // This also releases a consumed buffer.
      buffers[consumer_idx].to_be_consumed = false;
      __atomic_exchange(&shared_idx, &consumer_idx, &consumer_idx, __ATOMIC_ACQUIRE);
      return buffers[consumer_idx].to_be_consumed;
    };

    uint16_t* producer_buffer() {
      return buffers[producer_idx].data;
    }

    uint16_t* consumer_buffer() {
      return buffers[consumer_idx].data;
    }
};

struct SPIBus
{
  SPI_HandleTypeDef *hspi;
  const char *name;
  uint8_t midi_ch;          /* 0-based MIDI channel this side's notes play on */
  GPIO_TypeDef *nss_port;   /* NSS line, read to find the inter-frame gap */
  uint16_t nss_pin;

  TripleBuffer buffers;

  volatile uint8_t needs_resync;

  /* Per-reception outcome counters (updated in interrupt context). Every
   * reception is classified as exactly one of these, so
   * good + misaligned + crc_err + bus_err = total receptions:
   *   good       - completed and word 0 is a known wing id -> decoded
   *   misaligned - completed but word 0 is NOT a wing id (the 16-bit word
   *                boundaries don't line up with the wing's frame; the
   *                hardware CRC did not reject it) -> dropped
   *   crc_err    - HAL reported a CRC mismatch
   *   bus_err    - HAL reported overrun / mode / frame error */
  volatile uint32_t rx_good;
  volatile uint32_t rx_misaligned;
  volatile uint32_t crc_err;
  volatile uint32_t bus_err;
  volatile uint8_t  last_good_wing;  /* word 0 of the last good reception */
  volatile uint16_t last_bad_word0;  /* word 0 of the last misaligned reception */

  /* Per-key decode state (main-loop only). key_pressed tracks the physical
   * hall state; sounding_note is NOTE_NONE unless a NOTE ON has been sent for
   * that key without a matching NOTE OFF yet (key_pressed alone isn't enough
   * since a key can be held through a bellows direction change). */
  uint16_t key_min[SPI_LINK_NUM_KEYS];
  uint8_t  key_pressed[SPI_LINK_NUM_KEYS];
  uint8_t  sounding_note[SPI_LINK_NUM_KEYS];
  uint16_t mapped_keys_pressed;

  /* Last good frame's raw readings and their running statistics, for the
   * show_keyboard live report (main-loop only). */
  uint16_t    last_keys[SPI_LINK_NUM_KEYS];
  hall_stats_t hall;

  /* Snapshots for the 1 Hz rate report and the throttled error log. */
  uint32_t last_good, last_misaligned, last_crc, last_bus;
  uint32_t logged_crc, logged_bus, logged_misaligned, last_err_log_tick;

  /* Separate good-count snapshot for the live (show_spi) dashboard, so its rate
   * is computed over the report interval without disturbing the 1 Hz log above. */
  uint32_t rep_last_good, rep_last_tick;

  /* Silence-on-timeout: last tick a good frame was decoded in the main loop, and
   * a flag so the silence action fires exactly once per gap (re-armed on recovery). */
  uint32_t last_good_frame_tick;
  bool     timed_out;
};

static SPIBus g_bus[2];
// Increated in situation that should never happen.
static uint16_t g_spi_bus_state_error = 0;
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

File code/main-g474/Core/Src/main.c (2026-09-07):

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
/* Includes ------------------------------------------------------------------*/
#include "main.h"

/* USER CODE BEGIN Includes */
#include <stdio.h>
#include <stdlib.h>
#include <string.h>
#include "console.h"
#include "swo.h"
#include "usb_app.h"
#include "app/bellow.h"
#include "app/buttons.h"
#include "app/keyboard.h"
#include "app/pedals.h"
#include "app/report.h"
#include "properties.h"
#include "properties_console.h"
#include "app/midi.h"
#include "app/app.h"
/* Flash split and the DFU hand-off flag, shared with the bootloader. */
#include "memmap.h"

/* USER CODE END Includes */

ADC_HandleTypeDef hadc1;
ADC_HandleTypeDef hadc2;
ADC_HandleTypeDef hadc3;
ADC_HandleTypeDef hadc4;

SPI_HandleTypeDef hspi1;
SPI_HandleTypeDef hspi2;
DMA_HandleTypeDef hdma_spi1_rx;
DMA_HandleTypeDef hdma_spi2_rx;

UART_HandleTypeDef huart1;

PCD_HandleTypeDef hpcd_USB_FS;

void SystemClock_Config(void);
static void MX_GPIO_Init(void);
static void MX_DMA_Init(void);
static void MX_ADC1_Init(void);
static void MX_ADC2_Init(void);
static void MX_ADC3_Init(void);
static void MX_ADC4_Init(void);
static void MX_SPI1_Init(void);
static void MX_SPI2_Init(void);
static void MX_USART1_UART_Init(void);
static void MX_USB_PCD_Init(void);
/* USER CODE BEGIN 0 */

int console_execute(int argc, const char * const *argv)
{
  if (argc == 0)
    return 0;
  /* microrl ends the input line with LF only (no CR), leaving the cursor under
   * the command text. Return to column 0 so output prints cleanly below the
   * preserved "IRin > <cmd>" line instead of overwriting it. */
  printf("\r\n");
  if (strcmp(argv[0], "hello") == 0)
  {
    printf("Hello, Bandolibre!\r\n");
  }
  else if (strcmp(argv[0], "midi") == 0)
  {
    /* midi [note]: send a test note on/off pair over USB MIDI (default A4) */
    uint8_t note = (argc > 1) ? (uint8_t)atoi(argv[1]) : 69;
    usb_app_midi_test_note(note);
    printf("Sent MIDI note %u on/off\r\n", note);
  }
  else if (strcmp(argv[0], "dfu") == 0)
  {
    /* Reboot into the bootloader's mass storage mode, so firmware can be
     * updated without unplugging and holding FN2. The bootloader reads this
     * word, clears it, and stays in DFU mode; see boot-g474/main.c. */
#ifndef USER_VECT_TAB_ADDRESS
    /* Defined only for the Release build, which is the one that links above
     * the bootloader. A Debug image was flashed over the bootloader by
     * `just flash`, so there is nothing to reboot into. */
    printf("This is a Debug image flashed over the bootloader; there is no\r\n"
           "DFU mode to enter. Reinstall it with 'just flash_release'.\r\n");
#else
    printf("Rebooting into DFU mode; the BANDOLIBRE drive will appear.\r\n");
    HAL_Delay(50);   /* let the console UART drain before the reset */
    *(volatile uint32_t *)BOOT_FLAG_ADDR = BOOT_FLAG_MAGIC;
    NVIC_SystemReset();
#endif
  }
  else if (strcmp(argv[0], "bellow_tune") == 0) bellow_tune();
  else if (strcmp(argv[0], "help") == 0)   { properties_help(); midi_console_help(); }
  else if (properties_execute(argc, argv)) { /* handled show/get/set/reset */ }
  else if (midi_console_execute(argc, argv)) { /* handled a send_* command */ }
  else
    printf("Unknown command: %s (try 'help')\r\n", argv[0]);
  return 0;
}

/* Tab-completion for microrl: completes the command word, and the property name
 * argument of get/set/reset. Returns a NULL-terminated array of full tokens.
 * property_complete() caps its output at the buffer size, so growth is safe. */
#define CONSOLE_COMPL_MAX 32
char ** console_complete(int argc, const char * const *argv)
{
  static const char *commands[] = { "help", "show", "get", "set", "reset", "hello", "midi", "bellow_tune", "dfu" };
  static char *out[CONSOLE_COMPL_MAX + 1];
  const char *partial = (argc > 0) ? argv[argc - 1] : "";
  size_t n = 0;

  if (argc <= 1)
  {
    size_t plen = strlen(partial);
    for (size_t i = 0; i < sizeof(commands) / sizeof(commands[0]); i++)
      if (strncmp(commands[i], partial, plen) == 0)
        out[n++] = (char *)commands[i];
    const char *midi[CONSOLE_COMPL_MAX];
    size_t m = midi_console_complete(partial, midi, CONSOLE_COMPL_MAX - n);
    for (size_t i = 0; i < m; i++)
      out[n++] = (char *)midi[i];
  }
  else if (argc == 2 && (strcmp(argv[0], "get") == 0 ||
                         strcmp(argv[0], "set") == 0 ||
                         strcmp(argv[0], "reset") == 0))
  {
    const char *names[CONSOLE_COMPL_MAX];
    size_t m = properties_complete(partial, names, CONSOLE_COMPL_MAX);
    for (size_t i = 0; i < m; i++)
      out[n++] = (char *)names[i];
  }
  out[n] = NULL;
  return out;
}

/* USER CODE END 0 */

/**
  * @brief  The application entry point.
  * @retval int
  */
int main(void)
{

  /* MCU Configuration--------------------------------------------------------*/

  /* Reset of all peripherals, Initializes the Flash interface and the Systick. */
  HAL_Init();

  /* Configure the system clock */
  SystemClock_Config();

  /* Initialize all configured peripherals */
  MX_GPIO_Init();
  MX_DMA_Init();
  MX_ADC1_Init();
  MX_ADC2_Init();
  MX_ADC3_Init();
  MX_ADC4_Init();
  MX_SPI1_Init();
  MX_SPI2_Init();
  MX_USART1_UART_Init();
  MX_USB_PCD_Init();
  /* USER CODE BEGIN 2 */
  main_init();
  /* USER CODE END 2 */

  /* Infinite loop */
  /* USER CODE BEGIN WHILE */
  while (1)
  {
    /* USER CODE END WHILE */

    /* USER CODE BEGIN 3 */
    main_task();
  }
  /* USER CODE END 3 */
}

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


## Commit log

2024-01-19 Software SPI
2024-01-23 Optimize SPI
2024-01-26 Scan 40 sensors
2024-01-30 Add boards
    [bandoneon.kicad_sch, grape.kicad_sch]
2024-01-31 Design the board layout in kicad
2024-01-31 Design a cap
    [Cap.stl]
2024-02-04 Add key caps with various inner size
    [Cap-v1.stl, Cap-v2-cylinder-42.stl, Cap-v2-cylinder-45.stl]
2024-02-04 Remove pcb copy
2024-02-04 Use keyboard layout and set images DPI
    [bandoneon.kicad_sch, bandoneon.step, grape.kicad_sch]
2024-02-10 Schamtic complete
    [bandoneon.kicad_sch, bandoneon.step, grape.kicad_sch]
2024-02-10 Fix component side
    [bandoneon.kicad_sch, grape.kicad_sch, grape_alt.kicad_sch]
2024-02-15 Printing carter attempt.
    [Bottom L.stl, Bottom.stl, Top L.stl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]
2024-02-16 Document cap printing
2024-02-16 Add cap v2
    [Cap2-v3.stl]
2024-02-26 Add 1cm between two keyboards and ready for print test.
    [Bottom L.stl, Bottom.stl, Left Handle.stl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]
2024-02-26 Add strap screws
    [Bottom L.stl, Bottom.stl, Left Handle.stl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]
2024-02-26 Addjust holes with various sizes
    [Top L.stl]
2024-02-26 Larger Joystick hole
    [Top L.stl]
2024-03-01 Adjust caps
    [Cap.stl]
2024-03-07 Schema before wiring
    [bandoneon.kicad_sch, bandoneon.step, carter.dxf]
2024-03-08 PCB Check clear
2024-03-08 Ready for routing
    [grape.kicad_sch, grape_alt.kicad_sch]
2024-03-10 Manual routing
    [bandoneon.kicad_sch, grape.kicad_sch, grape_alt.kicad_sch]
2024-03-10 Fix refs before autoroute
    [freerouting.dsn, temp-freerouting.dsn]
2024-03-10 Add models and ground plane
    [grape.kicad_sch, grape_alt.kicad_sch]
2024-03-11 Complete manual wire
    [grape.kicad_sch, grape_alt.kicad_sch]
2024-03-11 Import back enforce
    [carter.dxf]
2024-03-14 Wiring fixed
    [bandoneon.kicad_sch, grape.kicad_sch, grape_alt.kicad_sch]
2024-03-16 More models.
    [Bottom L.stl, Bottom R.stl, Cap-v1.stl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]
2024-03-17 Add esd protection
    [bandoneon.kicad_sch, grape.kicad_sch, grape_alt.kicad_sch]
2024-03-18 Ready for print
    [Cap-v2-cylinder-415.stl, carter-split.step]
2024-03-18 Add screw and glue surface
    [carter v59.step]
2024-03-18 More glue surface.
    [Bottom L.stl, Bottom R.stl, Bottom.stl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]
2024-03-26 Before setting up the bom + pick and place
2024-03-27 Gerber and bom export
    [bandoneon-B_Cu.gbl, bandoneon-B_Mask.gbs, bandoneon-B_Paste.gbp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]
2024-03-28 Ready for fabrication
    [bandoneon-B_Cu.gbl, bandoneon-B_Mask.gbs, bandoneon-B_Paste.gbp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]
2024-03-30 PCB order
    [bandoneon-B_Cu.gbl, bandoneon-B_Mask.gbs, bandoneon-B_Paste.gbp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]
2024-03-30 Assembled breadboard test
2024-04-06 Program update on printed board.
2024-04-07 Fix jack footprint and wiring.
2024-04-07 Fix support and add pockets for pins
    [Bottom L.stl, Bottom R.stl]
2024-04-19 Remove step.
    [carter v51.step, carter v59.step, carter v62.step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]
2024-04-28 3dprint unsplit
    [Bottom L.stl, Bottom R.stl, Top L.stl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]
2024-04-30 Give up printing as a single part.
    [Bottom L.stl, Bottom R.stl, Handle L.stl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]
2024-05-22 Fix potentimeter glitchm and add neopixel support
    [01-25-instrument.ino]
2026-09-07 Continue project rename.
    [Bandolibre - Key - 72.3mf, Bandolibre - Key - slice.3mf]
2026-09-07 Use USB VID and PID sulicensed by STM32.
2026-09-07 Make wing just file independent from main.
    Also enable fallback so that console is available everywhere.
2026-09-10 Force fixed velocity and cc#11 in table mode.
    [bellow.c, keyboard.cpp]
2026-09-10 Add flash_release to the wing board scripts.
2026-10-17 Main board: drive the hall supply gate push-pull.
    - Regenerated with CubeMX; HALL_NEN is now initialised together with L_BOOT0.
2026-10-18 Wing: power the hall supply only during each scan and report loop timings.
    - The hall supply is off between scans; HALL_POWER_SETTLE_CYCLES is untuned.
    - The live report shows scan, transmit, other and report time per loop.
2026-10-18 Wing: add a report console command to toggle the periodic report.
2026-10-18 Wing: keep the ADCs enabled and only rearm the DMA channels each scan.
    - The scan rate goes from 1260 to 1448 Hz.
    - The DMA half and full transfer interrupts are off.
2026-10-18 Wing: turn the periodic report off by default.
2026-10-18 Wing: drive the hall supply gate push-pull.
2026-10-18 Wing: add scan_period, settle and mux console commands.
    - scan_period limits the scan rate with a minimum period.
    - settle and mux set the hall supply and mux select delays at runtime.
    - The default mux delay is an estimate of the old fixed loop.
2026-10-18 Wing: add a tune command and set the hall settle and mux delays to 20 us and 1 us.
    - tune scans a grid of settle and mux delays and recommends values.
    - The default scan is now about 44 us.
2026-10-18 Wing: widen the tune grids, add a per-key report and judge shifts against noise.
    - The mux grid goes to 12 us and the settle grid to 300 us.
    - The reference is measured again before each settle row, and its drift is printed.
    - The shift limits are at least half the noise standard deviation.
    - tune lists the keys that need a longer hall power settle.
2026-10-18 Wing: rename the hall power settle to g_power_settle_ns and use nanoseconds.
    - The settle command now takes nanoseconds.
2026-10-20 Report: replace report_hz with report_period_ms, up to 10 s.
    - The dashboard rule line shows the period in ms instead of Hz, on both boards.
    - A saved report_hz value is read as milliseconds: reset report_period_ms once.
2026-10-24 MIDI tool: add an install button for the PWA.

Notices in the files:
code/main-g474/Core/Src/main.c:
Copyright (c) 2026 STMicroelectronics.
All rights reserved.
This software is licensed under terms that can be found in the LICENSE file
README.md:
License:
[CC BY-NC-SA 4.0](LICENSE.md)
